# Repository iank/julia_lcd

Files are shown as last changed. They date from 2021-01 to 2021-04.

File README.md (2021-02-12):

# julia_lcd

TFT LCD panel, capacitive touch controller, Xilinx Cyclone IV FPGA, SDR SDRAM

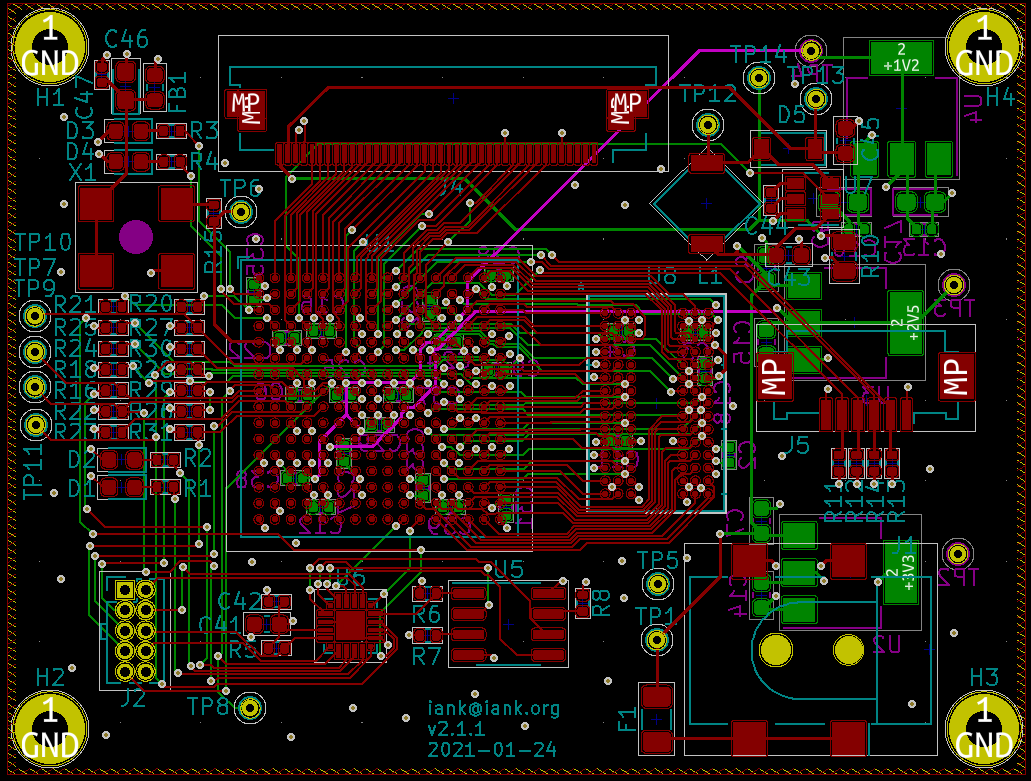
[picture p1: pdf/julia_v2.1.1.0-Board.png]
Board image

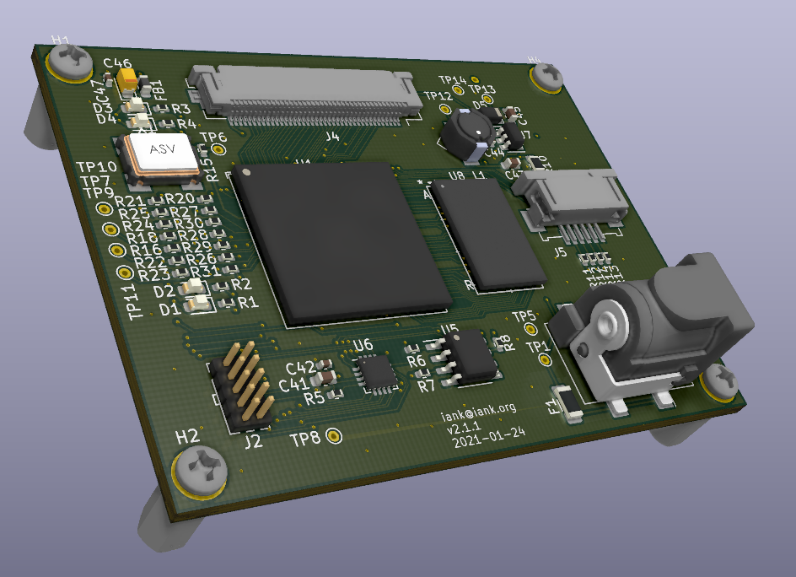
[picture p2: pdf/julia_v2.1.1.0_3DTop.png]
3D View (Top)

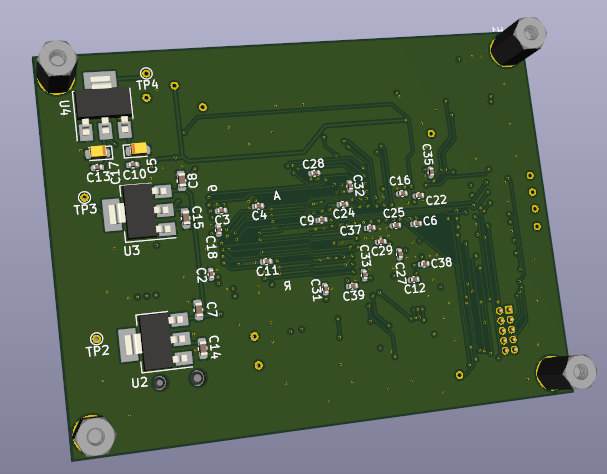
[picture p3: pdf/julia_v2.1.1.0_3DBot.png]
3D View (Bottom)


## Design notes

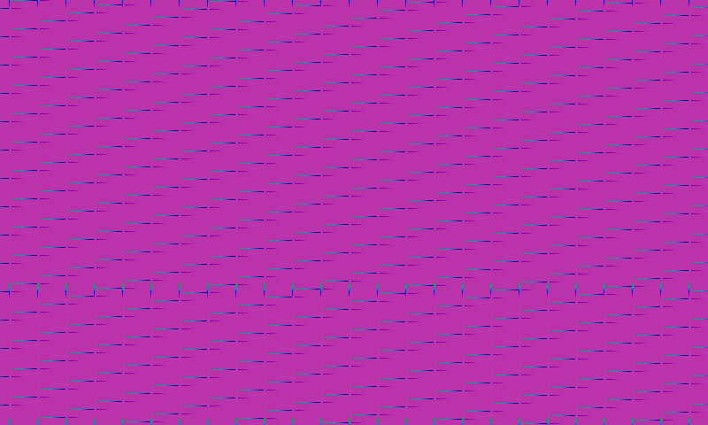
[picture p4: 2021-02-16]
src/fpga/img/verilog_sim.png

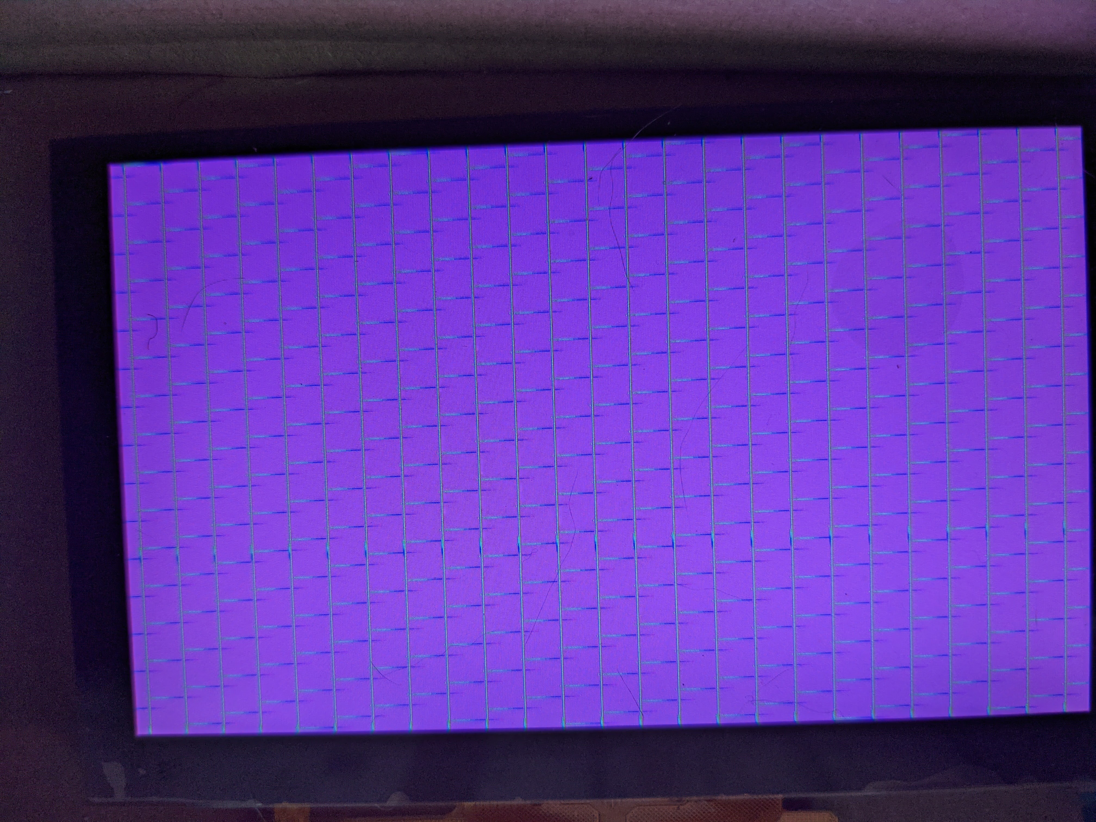
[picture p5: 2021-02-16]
src/fpga/img/actual.jpg

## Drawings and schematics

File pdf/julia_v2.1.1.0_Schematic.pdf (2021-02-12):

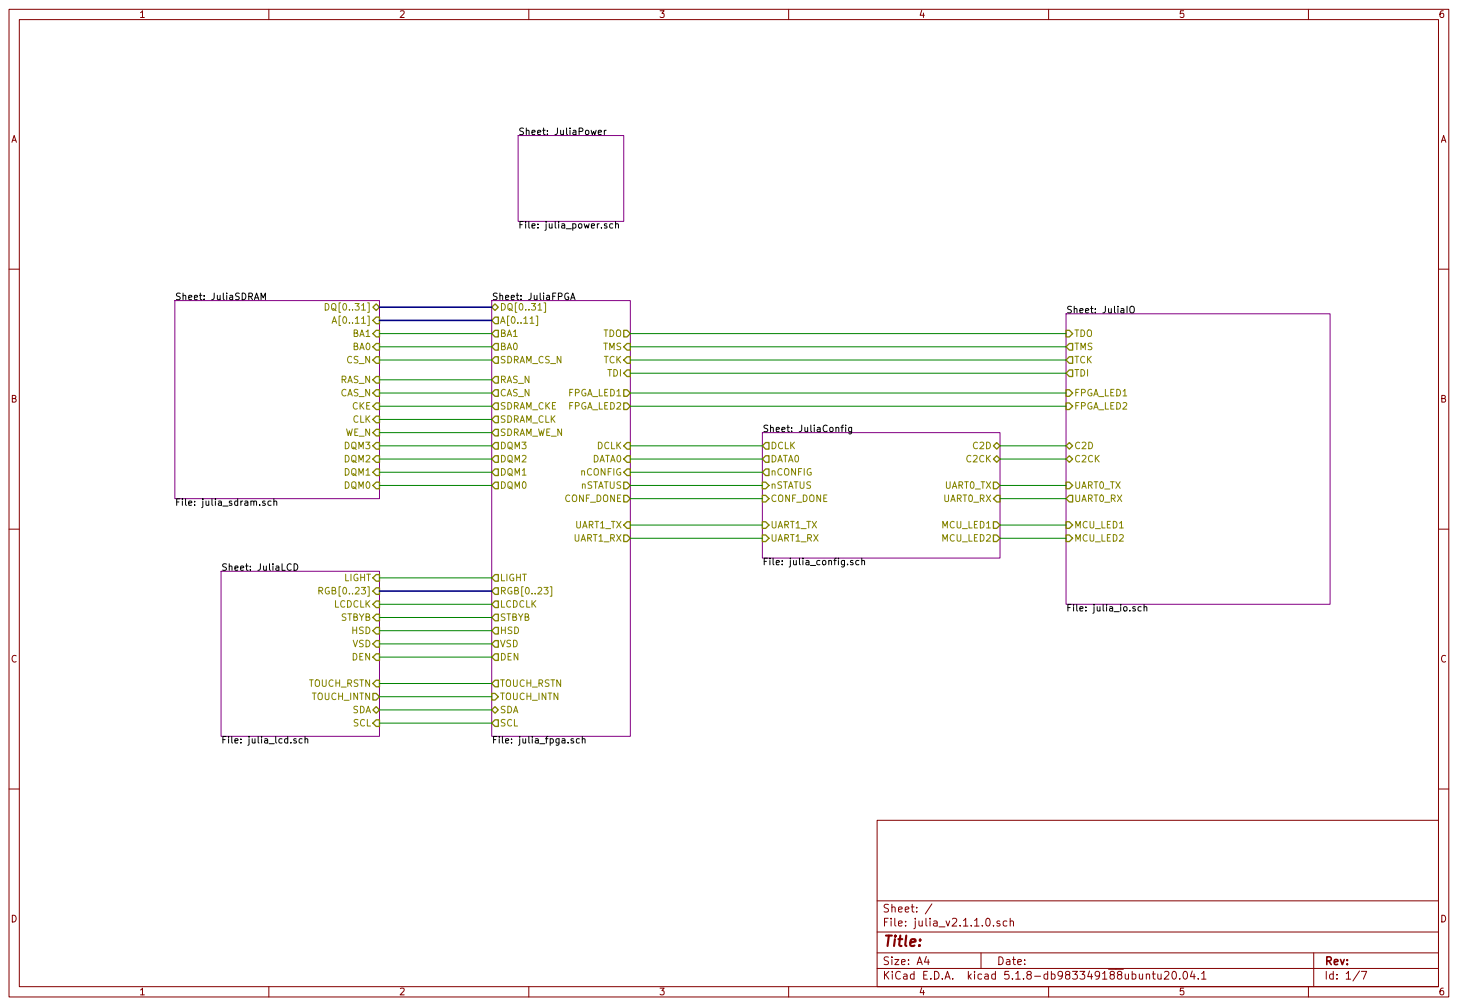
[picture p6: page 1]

Sheet: JuliaPower File: julia_power.sch Sheet: JuliaSDRAM

Sheet: JuliaIO
File: julia_io.sch TDI TMS
TCK

CKE CLK DQM3 DQM2 DQM1 DQM0 Sheet: JuliaLCD

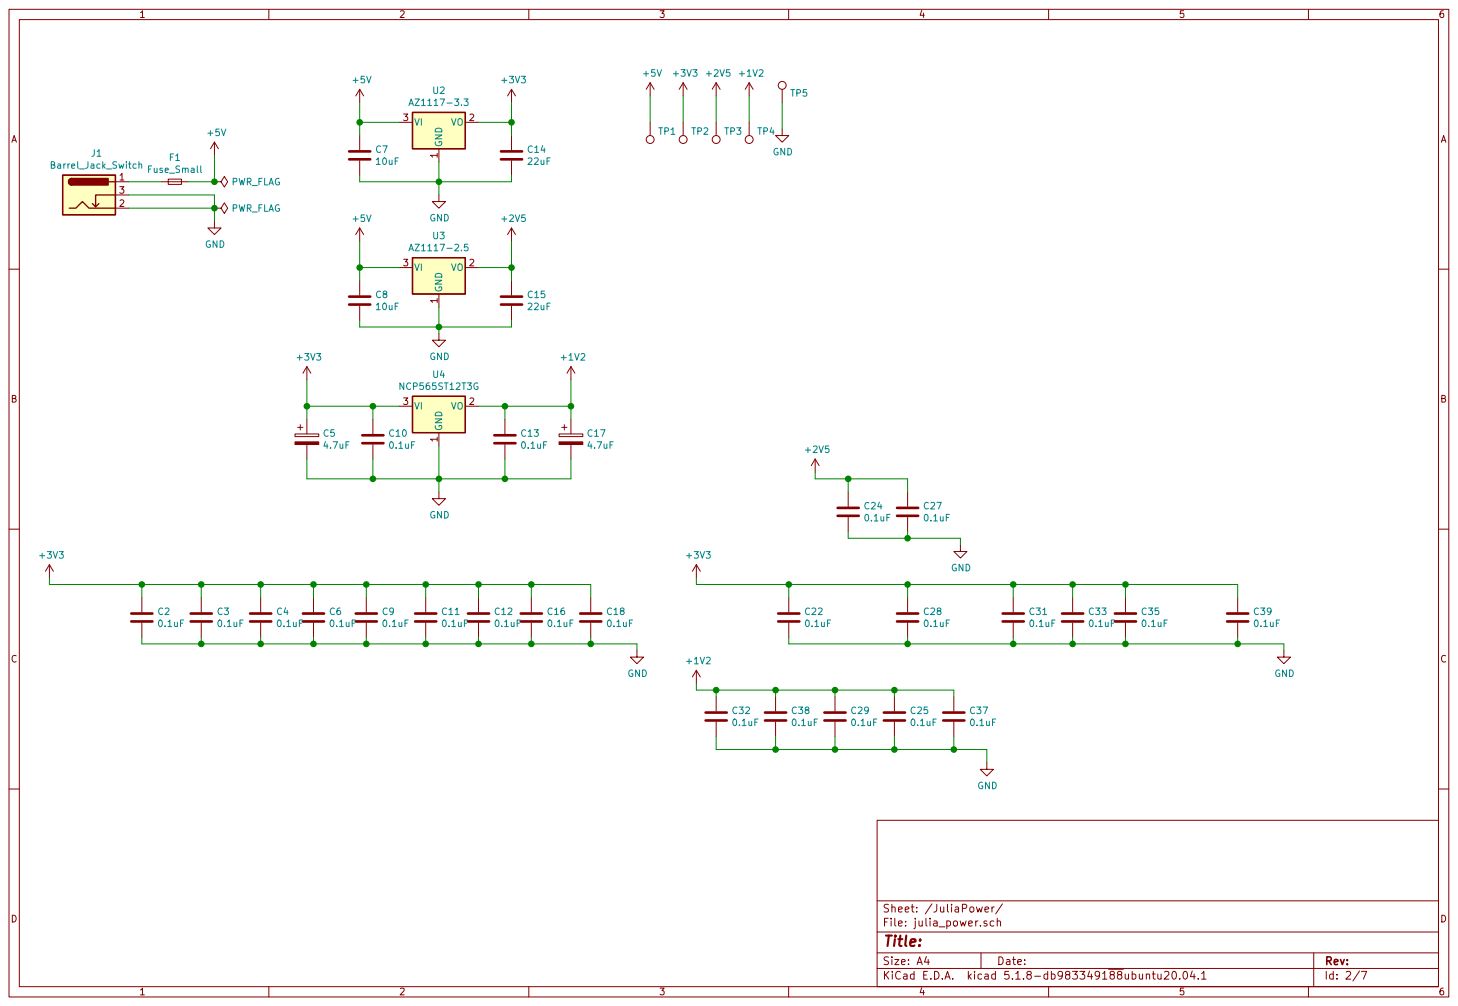
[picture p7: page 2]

File: julia_power.sch Sheet: /JuliaPower/
Id: 2/7 Title:

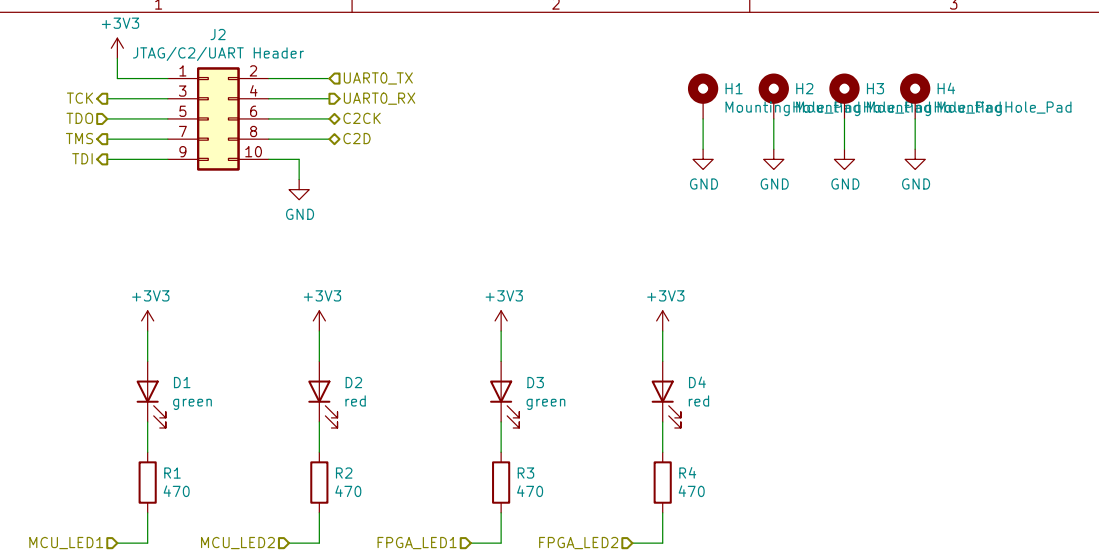
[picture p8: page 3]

File: julia_io.sch Sheet: /JuliaIO/
Id: 3/7 Title:

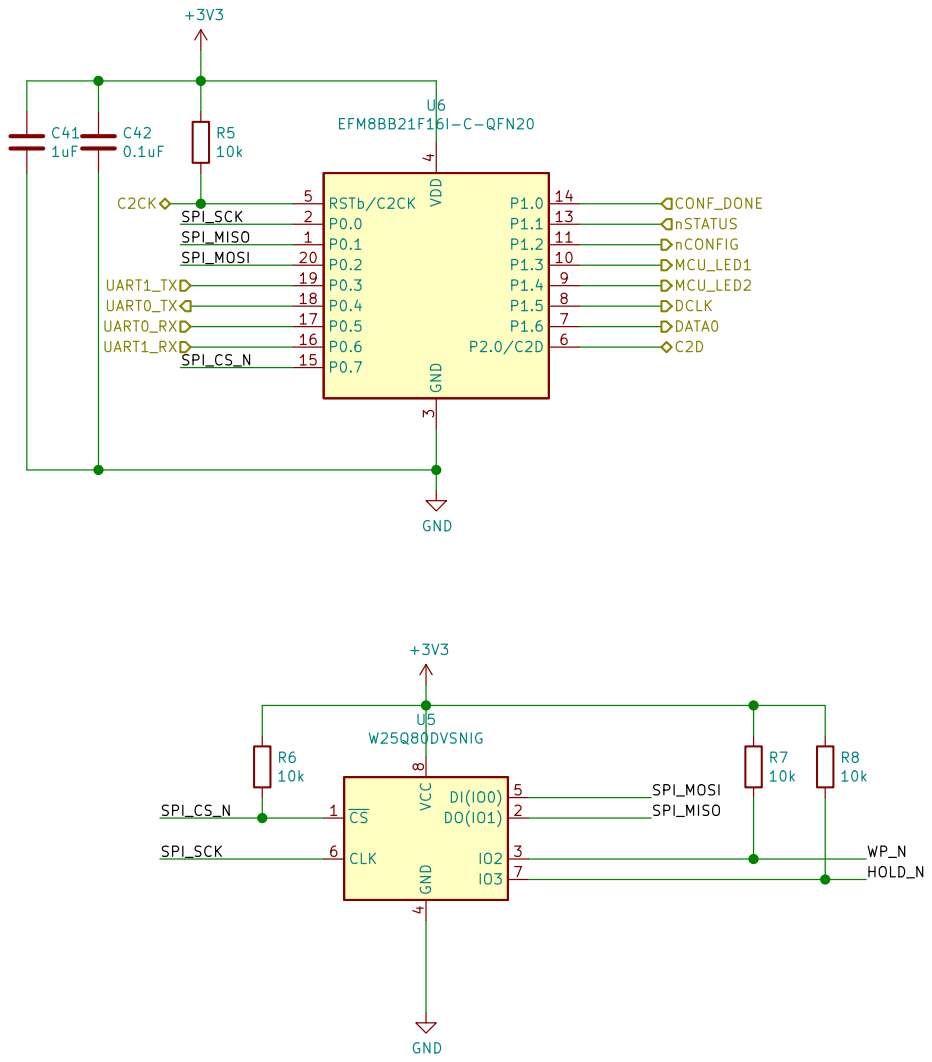
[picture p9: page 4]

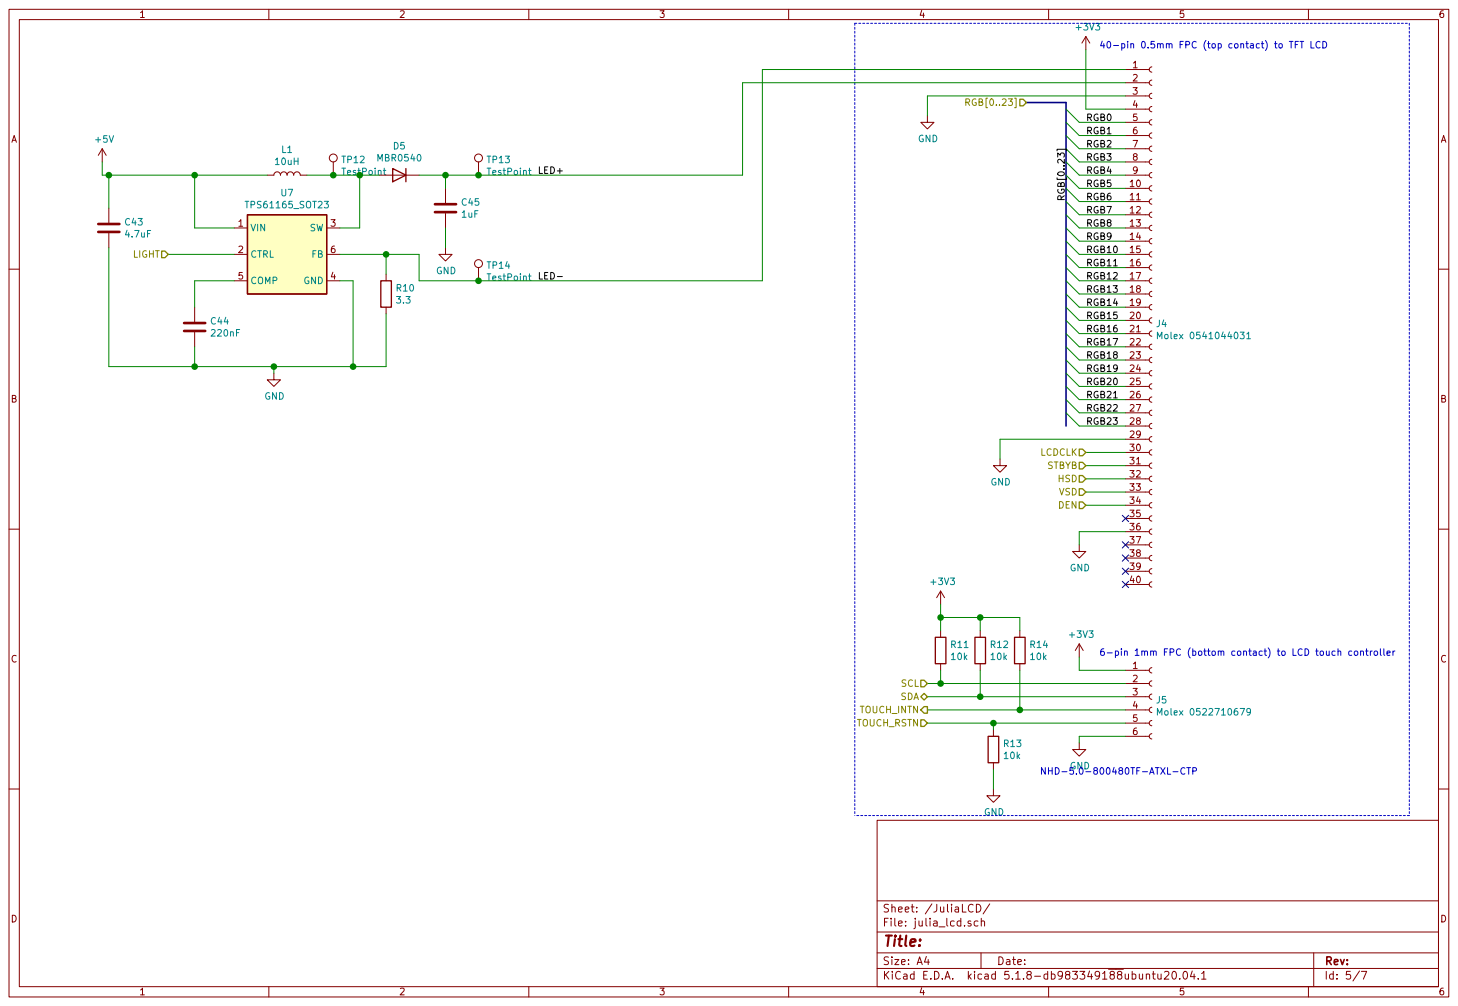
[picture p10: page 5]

40-pin 0.5mm FPC (top contact) to TFT LCD

6-pin 1mm FPC (bottom contact) to LCD touch controller NHD-5.0-800480TF-ATXL-CTP

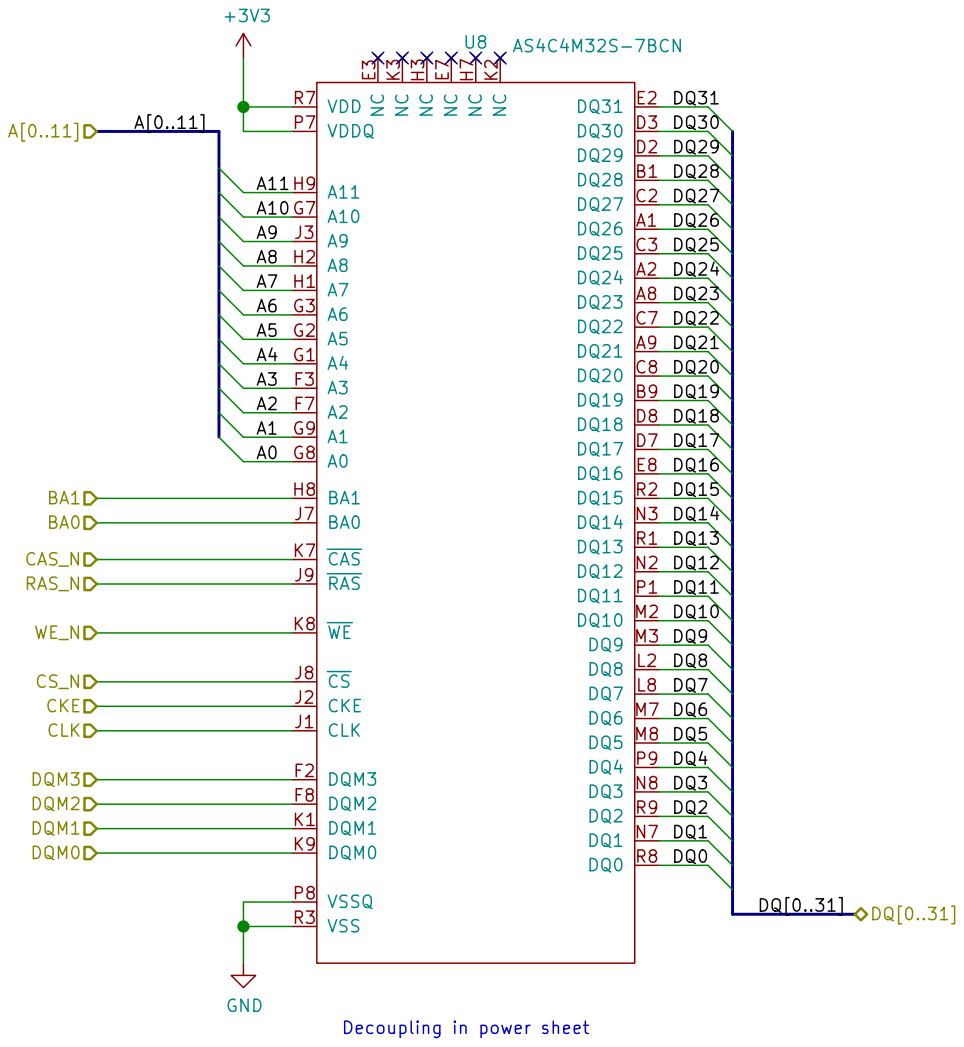
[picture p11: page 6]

File: julia_sdram.sch Sheet: /JuliaSDRAM/

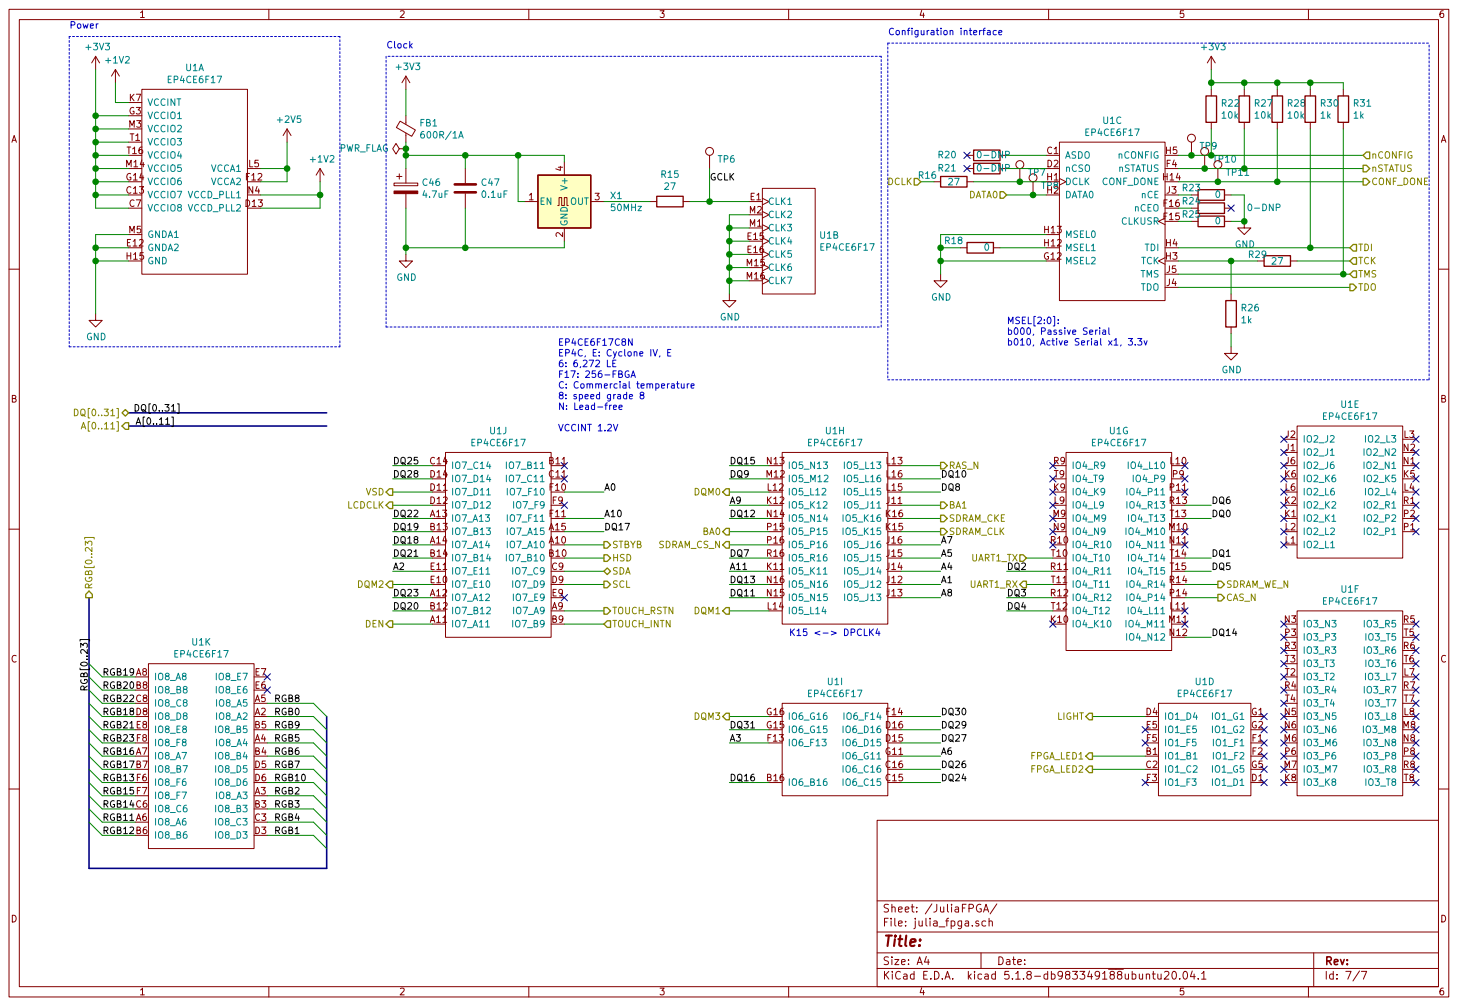
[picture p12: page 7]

File: julia_fpga.sch Sheet: /JuliaFPGA/
Id: 7/7 Title:

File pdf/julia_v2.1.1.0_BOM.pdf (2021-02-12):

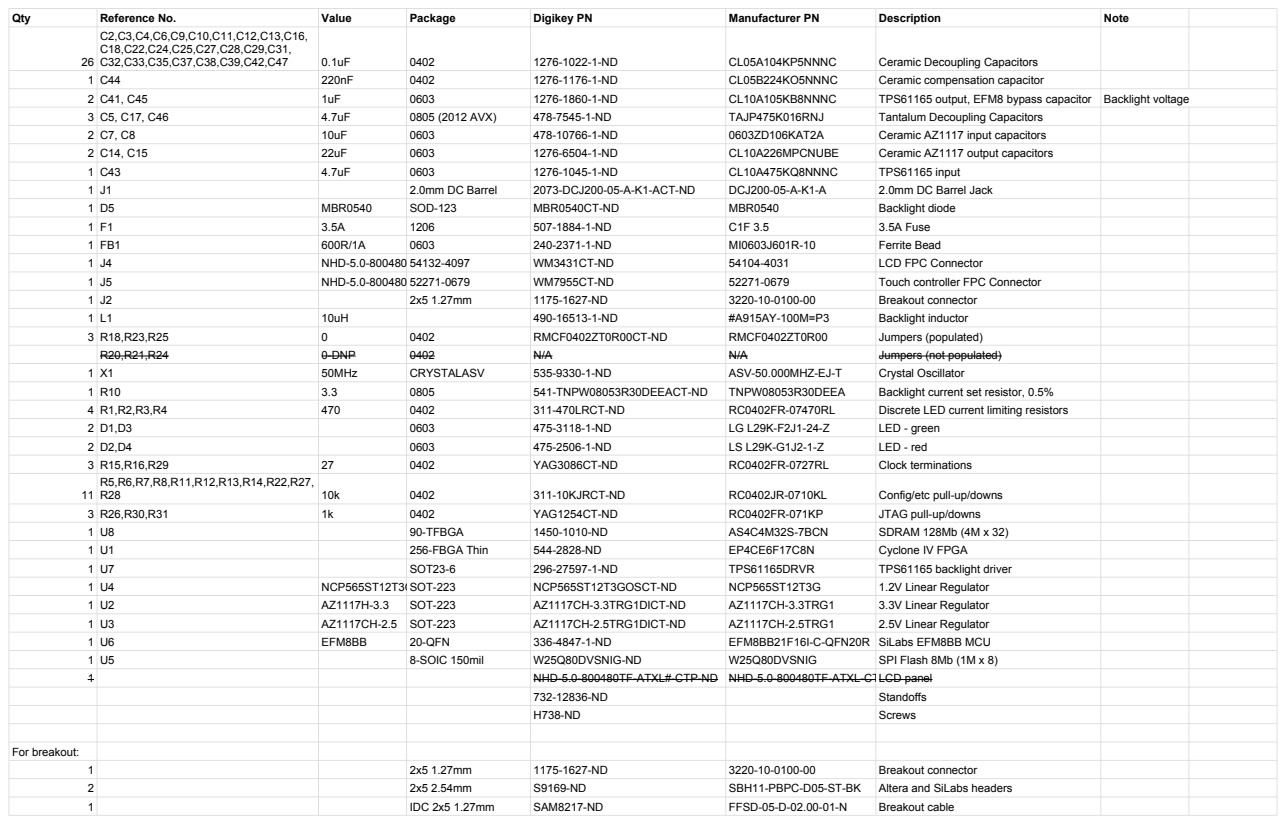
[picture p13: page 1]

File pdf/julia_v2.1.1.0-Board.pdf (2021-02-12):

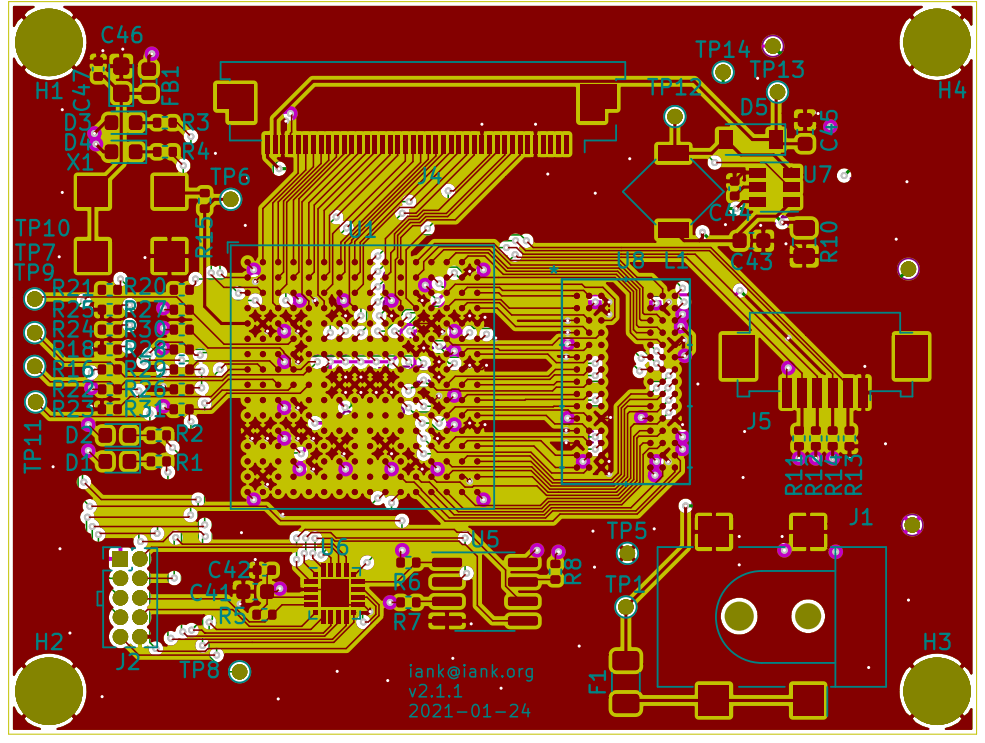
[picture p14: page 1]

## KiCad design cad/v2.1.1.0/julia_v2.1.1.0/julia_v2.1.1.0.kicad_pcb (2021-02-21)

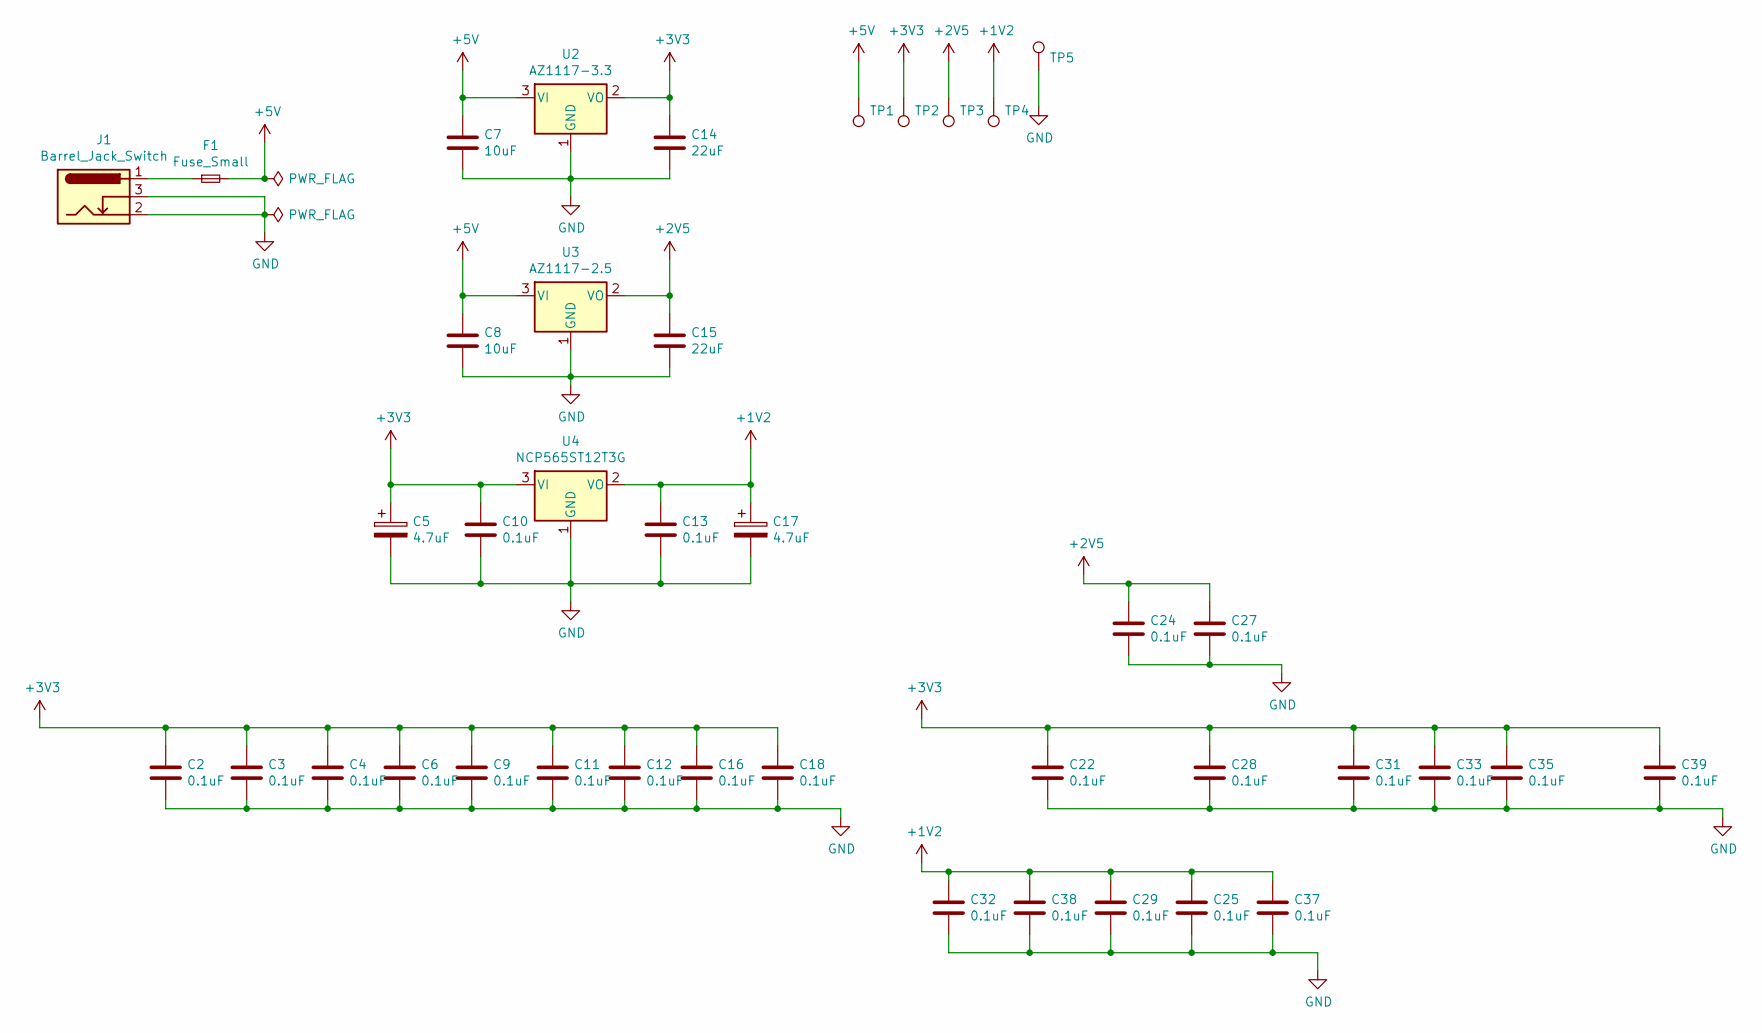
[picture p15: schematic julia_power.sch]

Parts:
C2, C3, C4, C6, C9, C10, C11, C12, C13, C16, C18, C22, C24, C25, C27, C28, C29, C31, C32, C33, C35, C37, C38, C39: 0.1uF; C_0402_1005Metric
C5, C17: 4.7uF; CP_EIA-2012-15_AVX-P
C7, C8: 10uF; C_0603_1608Metric
C14, C15: 22uF; C_0603_1608Metric
F1: Fuse_Small; Fuse_1206_3216Metric
J1: Barrel_Jack_Switch; BarrelJack_GCT_DCJ200-05-A-K1-A_SMD_Horizontal
TP1, TP2, TP3, TP4, TP5: TestPoint; TestPoint_THTPad_D1.0mm_Drill0.5mm
U2: AZ1117-3.3; SOT-223-3_TabPin2
U3: AZ1117-2.5; SOT-223-3_TabPin2
U4: NCP565ST12T3G; SOT-223-3_TabPin2

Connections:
+1V2: C13.1, C17.1, C25.1, C29.1, C32.1, C37.1, C38.1, TP4.1, U4.2 (VO); also elsewhere on the board
+2V5: C15.1, C24.1, C27.1, TP3.1, U3.2 (VO); also elsewhere on the board
+3V3: C2.1, C3.1, C4.1, C5.1, C6.1, C9.1, C10.1, C11.1, C12.1, C14.1, C16.1, C18.1, C22.1, C28.1, C31.1, C33.1, C35.1, C39.1, TP2.1, U2.2 (VO), U4.3 (VI); also elsewhere on the board
+5V: C7.1, C8.1, F1.2, TP1.1, U2.3 (VI), U3.3 (VI); also elsewhere on the board
GND: C2.2, C3.2, C4.2, C5.2, C6.2, C7.2, C8.2, C9.2, C10.2, C11.2, C12.2, C13.2, C14.2, C15.2, C16.2, C17.2, C18.2, C22.2, C24.2, C25.2, C27.2, C28.2, C29.2, C31.2, C32.2, C33.2, C35.2, C37.2, C38.2, C39.2, J1.2, J1.3, TP5.1, U2.1 (GND), U3.1 (GND), U4.1 (GND); also elsewhere on the board
unnamed: F1.1, J1.1

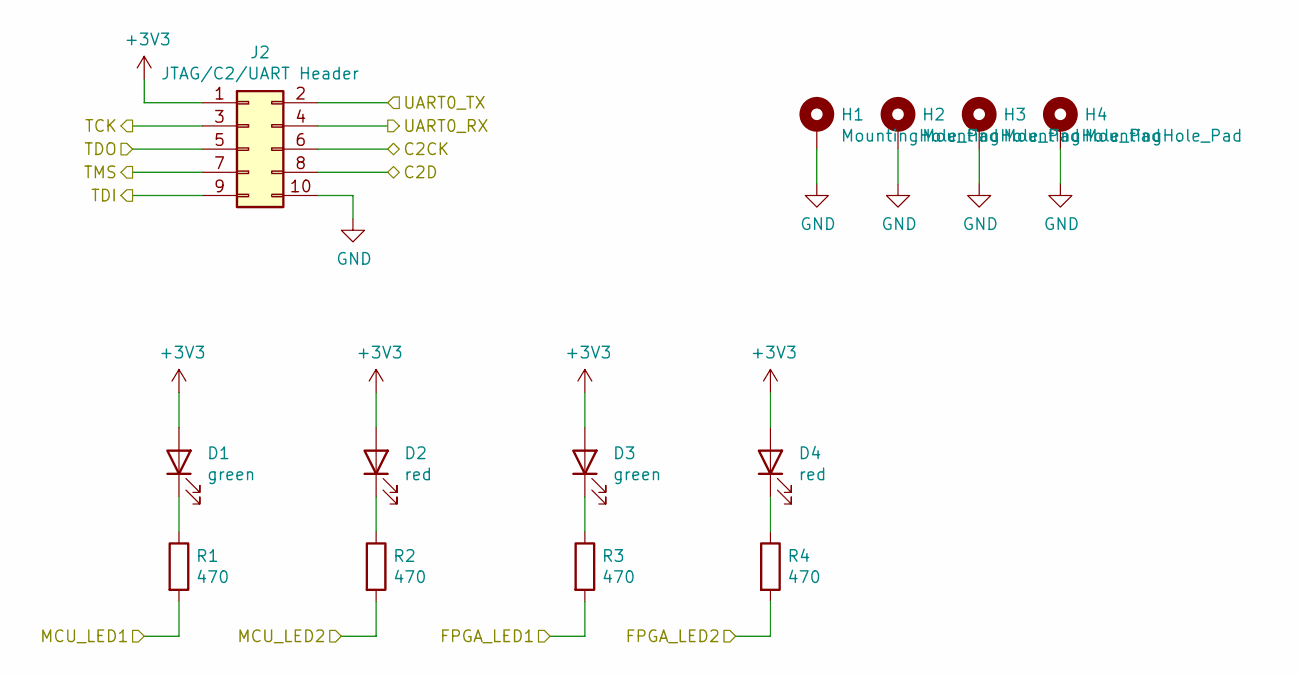
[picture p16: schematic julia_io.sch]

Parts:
D1, D3: green; LED_0603_1608Metric
D2, D4: red; LED_0603_1608Metric
H1, H2, H3, H4: MountingHole_Pad; MountingHole_2.2mm_M2_Pad
J2: JTAG/C2/UART Header; PinHeader_2x05_P1.27mm_Vertical
R1, R2, R3, R4: 470; R_0402_1005Metric

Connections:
+3V3: D1.2 (A), D2.2 (A), D3.2 (A), D4.2 (A), J2.1; also elsewhere on the board
/JuliaConfig/C2CK: J2.6; also elsewhere on the board
/JuliaConfig/C2D: J2.8; also elsewhere on the board
/JuliaConfig/MCU_LED1: R1.2; also elsewhere on the board
/JuliaConfig/MCU_LED2: R2.2; also elsewhere on the board
/JuliaConfig/UART0_RX: J2.4; also elsewhere on the board
/JuliaConfig/UART0_TX: J2.2; also elsewhere on the board
/JuliaFPGA/FPGA_LED1: R3.2; also elsewhere on the board
/JuliaFPGA/FPGA_LED2: R4.2; also elsewhere on the board
/JuliaFPGA/TCK: J2.3; also elsewhere on the board
/JuliaFPGA/TDI: J2.9; also elsewhere on the board
/JuliaFPGA/TDO: J2.5; also elsewhere on the board
/JuliaFPGA/TMS: J2.7; also elsewhere on the board
GND: H1.1, H2.1, H3.1, H4.1, J2.10; also elsewhere on the board
unnamed: D1.1 (K), R1.1
unnamed: D2.1 (K), R2.1
unnamed: D3.1 (K), R3.1
unnamed: D4.1 (K), R4.1

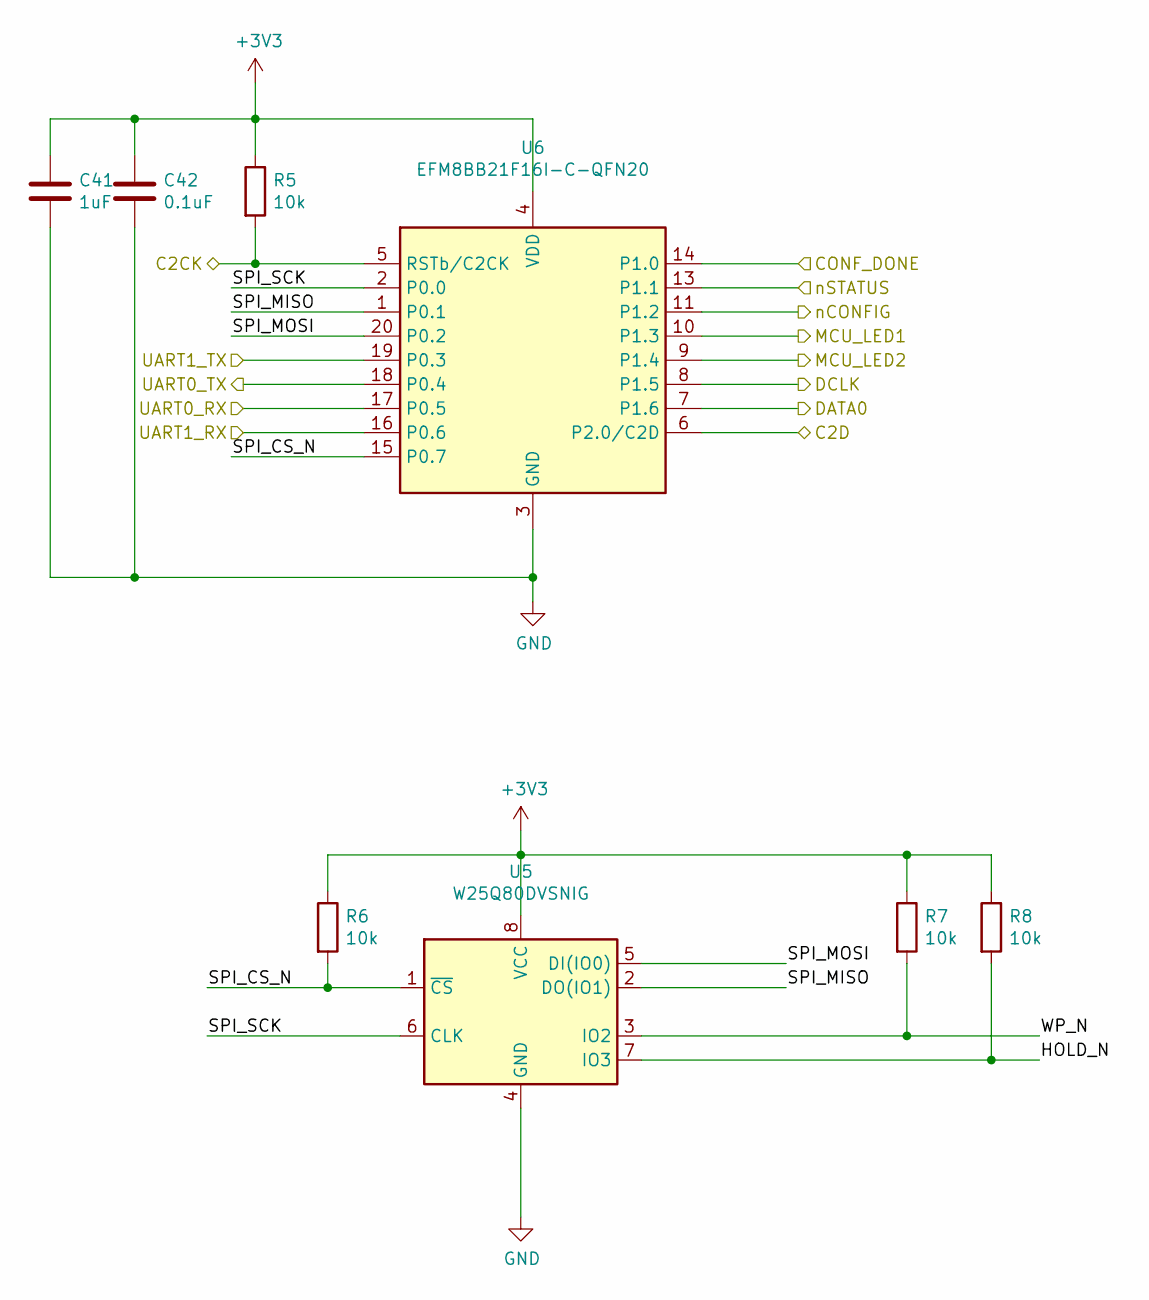
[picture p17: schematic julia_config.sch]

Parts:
C41: 1uF; C_0603_1608Metric
C42: 0.1uF; C_0402_1005Metric
R5, R6, R7, R8: 10k; R_0402_1005Metric
U5: W25Q80DVSNIG; SOIC-8_3.9x4.9mm_P1.27mm
U6: EFM8BB21F16I-C-QFN20; SiliconLabs_QFN-20-1EP_3x3mm_P0.5mm_EP1.8x1.8mm

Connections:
+3V3: C41.1, C42.1, R5.1, R6.1, R7.1, R8.1, U5.8 (VCC), U6.4 (VDD); also elsewhere on the board
/JuliaConfig/C2CK: R5.2, U6.5 (RSTb/C2CK); also elsewhere on the board
/JuliaConfig/C2D: U6.6 (P2.0/C2D); also elsewhere on the board
/JuliaConfig/CONF_DONE: U6.14 (P1.0); also elsewhere on the board
/JuliaConfig/DATA0: U6.7 (P1.6); also elsewhere on the board
/JuliaConfig/DCLK: U6.8 (P1.5); also elsewhere on the board
/JuliaConfig/HOLD_N: R8.2, U5.7 (IO3)
/JuliaConfig/MCU_LED1: U6.10 (P1.3); also elsewhere on the board
/JuliaConfig/MCU_LED2: U6.9 (P1.4); also elsewhere on the board
/JuliaConfig/SPI_CS_N: R6.2, U5.1 (~CS), U6.15 (P0.7)
/JuliaConfig/SPI_MISO: U5.2 (DO(IO1)), U6.1 (P0.1)
/JuliaConfig/SPI_MOSI: U5.5 (DI(IO0)), U6.20 (P0.2)
/JuliaConfig/SPI_SCK: U5.6 (CLK), U6.2 (P0.0)
/JuliaConfig/UART0_RX: U6.17 (P0.5); also elsewhere on the board
/JuliaConfig/UART0_TX: U6.18 (P0.4); also elsewhere on the board
/JuliaConfig/UART1_RX: U6.16 (P0.6); also elsewhere on the board
/JuliaConfig/UART1_TX: U6.19 (P0.3); also elsewhere on the board
/JuliaConfig/WP_N: R7.2, U5.3 (IO2)
/JuliaConfig/nCONFIG: U6.11 (P1.2); also elsewhere on the board
/JuliaConfig/nSTATUS: U6.13 (P1.1); also elsewhere on the board
GND: C41.2, C42.2, U5.4 (GND), U6.3 (GND), U6.12 (GND), U6.21 (GND); also elsewhere on the board

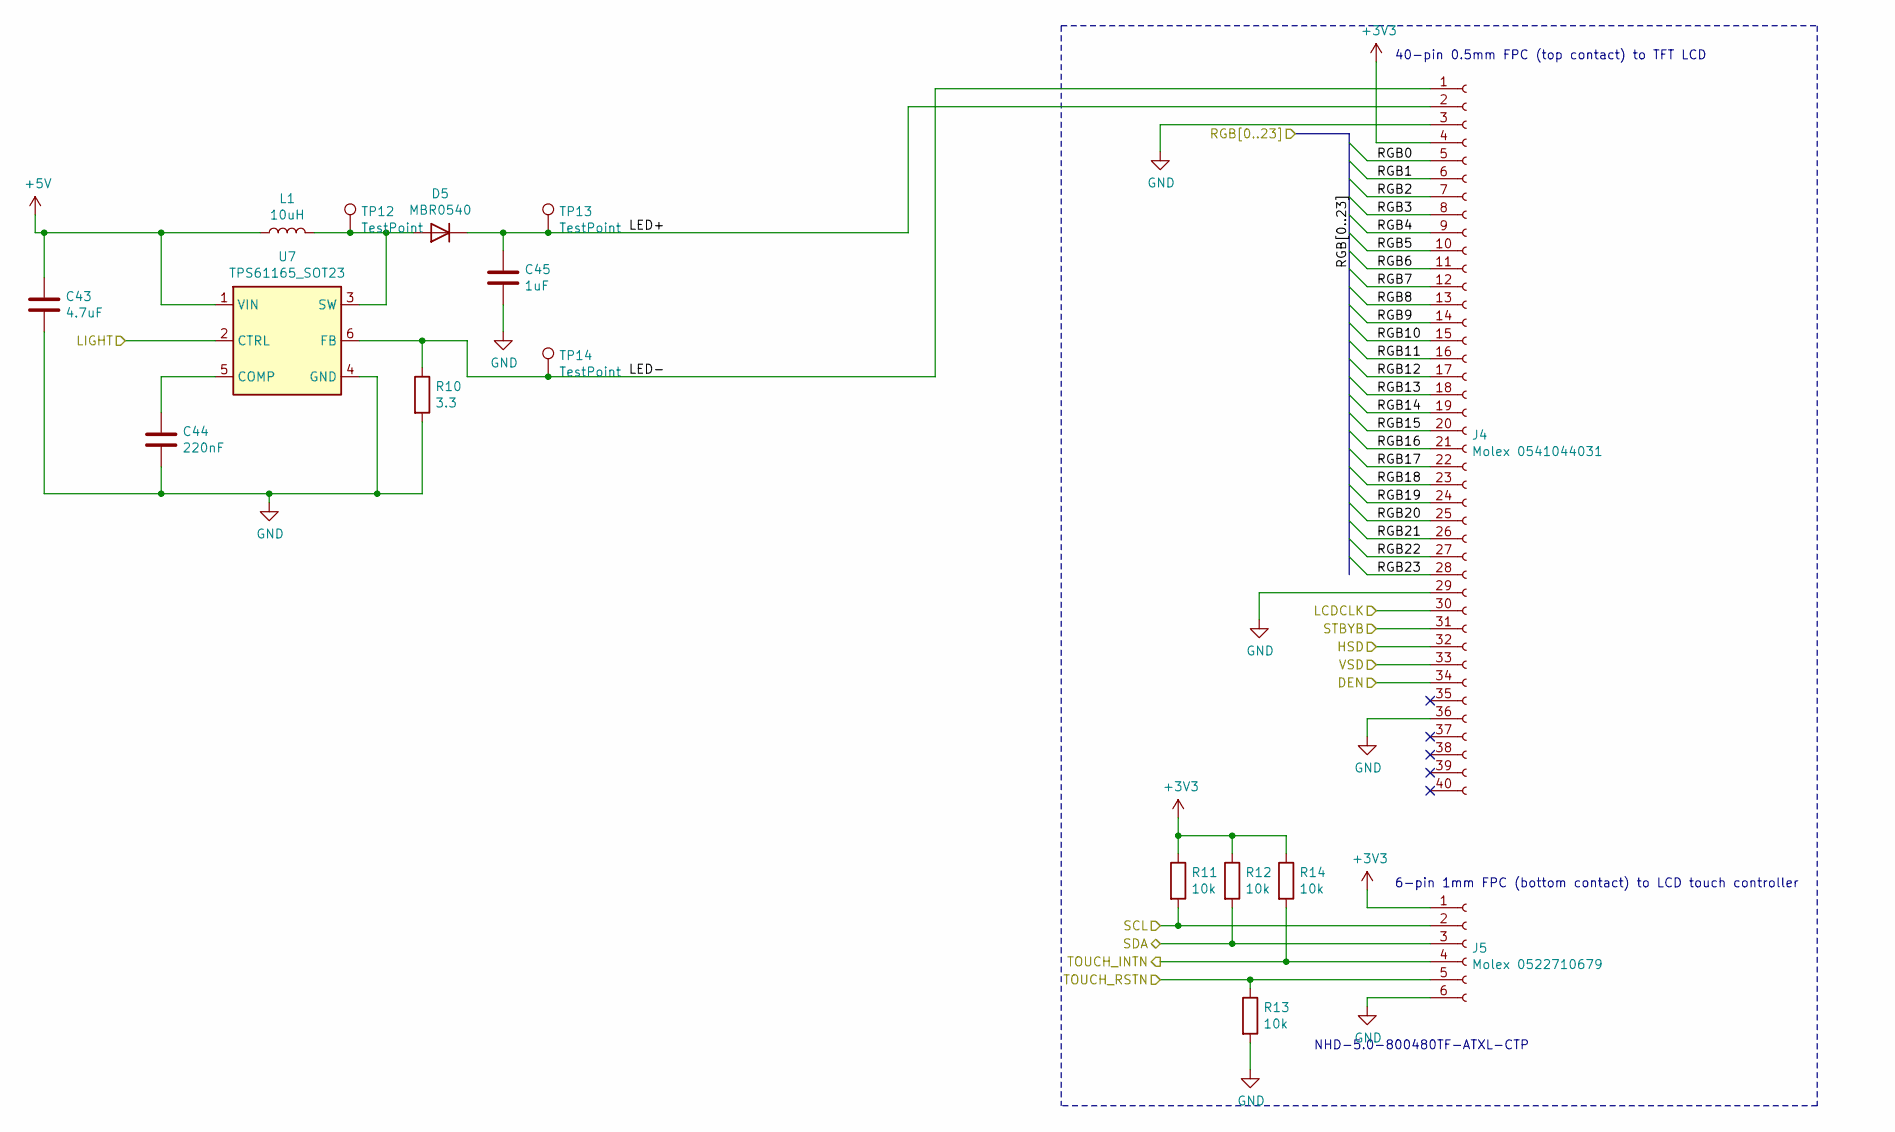
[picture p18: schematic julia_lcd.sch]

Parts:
C43: 4.7uF; C_0603_1608Metric
C44: 220nF; C_0402_1005Metric
C45: 1uF; C_0603_1608Metric
D5: MBR0540; D_SOD-123
J4: Molex 0541044031; Molex_54104-4031_1x40-P0.5mm_Horizontal
J5: Molex 0522710679; Molex_52271-0679_1x06-1MP_P1.00mm_Horizontal
L1: 10uH; Murata_D53LC_A915AY-100M
R10: 3.3; R_0805_2012Metric
R11, R12, R13, R14: 10k; R_0402_1005Metric
TP12, TP13, TP14: TestPoint; TestPoint_THTPad_D1.0mm_Drill0.5mm
U7: TPS61165_SOT23; SOT-23-6

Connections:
+3V3: J4.4, J5.1, R11.1, R12.1, R14.1; also elsewhere on the board
+5V: C43.1, L1.1, U7.1 (VIN); also elsewhere on the board
/JuliaFPGA/DEN: J4.34; also elsewhere on the board
/JuliaFPGA/HSD: J4.32; also elsewhere on the board
/JuliaFPGA/LCDCLK: J4.30; also elsewhere on the board
/JuliaFPGA/LIGHT: U7.2 (CTRL); also elsewhere on the board
/JuliaFPGA/RGB0: J4.5; also elsewhere on the board
/JuliaFPGA/RGB1: J4.6; also elsewhere on the board
/JuliaFPGA/RGB2: J4.7; also elsewhere on the board
/JuliaFPGA/RGB3: J4.8; also elsewhere on the board
/JuliaFPGA/RGB4: J4.9; also elsewhere on the board
/JuliaFPGA/RGB5: J4.10; also elsewhere on the board
/JuliaFPGA/RGB6: J4.11; also elsewhere on the board
/JuliaFPGA/RGB7: J4.12; also elsewhere on the board
/JuliaFPGA/RGB8: J4.13; also elsewhere on the board
/JuliaFPGA/RGB9: J4.14; also elsewhere on the board
/JuliaFPGA/RGB10: J4.15; also elsewhere on the board
/JuliaFPGA/RGB11: J4.16; also elsewhere on the board
/JuliaFPGA/RGB12: J4.17; also elsewhere on the board
/JuliaFPGA/RGB13: J4.18; also elsewhere on the board
/JuliaFPGA/RGB14: J4.19; also elsewhere on the board
/JuliaFPGA/RGB15: J4.20; also elsewhere on the board
/JuliaFPGA/RGB16: J4.21; also elsewhere on the board
/JuliaFPGA/RGB17: J4.22; also elsewhere on the board
/JuliaFPGA/RGB18: J4.23; also elsewhere on the board
/JuliaFPGA/RGB19: J4.24; also elsewhere on the board
/JuliaFPGA/RGB20: J4.25; also elsewhere on the board
/JuliaFPGA/RGB21: J4.26; also elsewhere on the board
/JuliaFPGA/RGB22: J4.27; also elsewhere on the board
/JuliaFPGA/RGB23: J4.28; also elsewhere on the board
/JuliaFPGA/SCL: J5.2, R11.2; also elsewhere on the board
/JuliaFPGA/SDA: J5.3, R12.2; also elsewhere on the board
/JuliaFPGA/STBYB: J4.31; also elsewhere on the board
/JuliaFPGA/TOUCH_INTN: J5.4, R14.2; also elsewhere on the board
/JuliaFPGA/TOUCH_RSTN: J5.5, R13.1; also elsewhere on the board
/JuliaFPGA/VSD: J4.33; also elsewhere on the board
/JuliaLCD/LED+: C45.1, D5.1 (K), J4.2, TP13.1
/JuliaLCD/LED-: J4.1, R10.1, TP14.1, U7.6 (FB)
GND: C43.2, C44.2, C45.2, J4.3, J4.29, J4.36, J5.6, R10.2, R13.2, U7.4 (GND); also elsewhere on the board
unnamed: C44.1, U7.5 (COMP)
unnamed: D5.2 (A), L1.2, TP12.1, U7.3 (SW)

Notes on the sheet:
40-pin 0.5mm FPC (top contact) to TFT LCD
NHD-5.0-800480TF-ATXL-CTP
6-pin 1mm FPC (bottom contact) to LCD touch controller

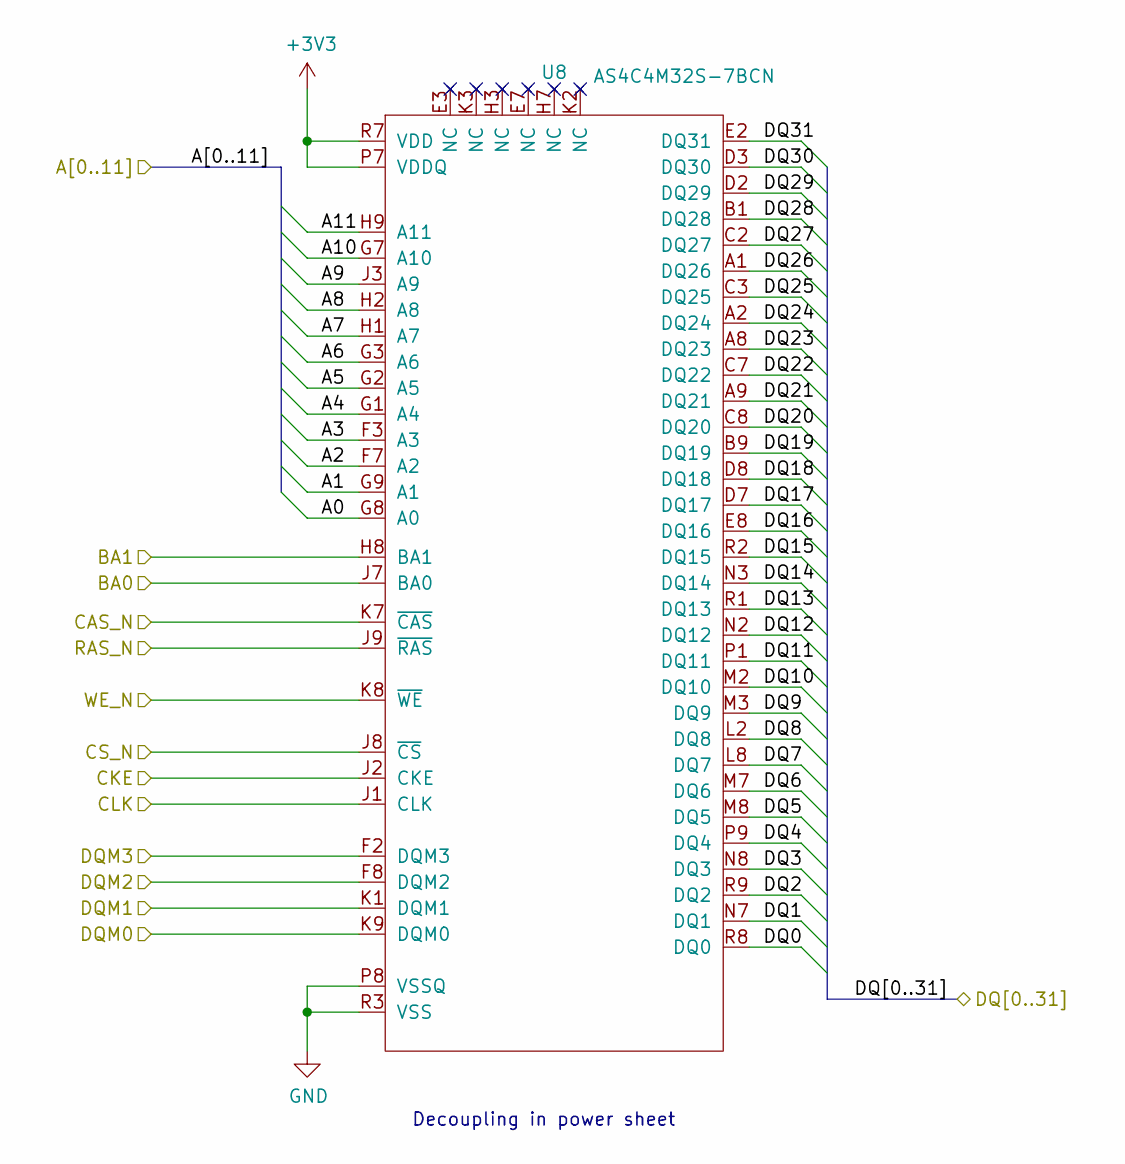
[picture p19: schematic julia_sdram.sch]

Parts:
U8: AS4C4M32S-7BCN

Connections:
+3V3: U8.A7 (VDD), U8.B2 (VDDQ), U8.B7 (VDDQ), U8.C9 (VDDQ), U8.D9 (VDDQ), U8.E1 (VDDQ), U8.F9 (VDD), U8.L1 (VDDQ), U8.L7 (VDD), U8.M9 (VDDQ), U8.N9 (VDDQ), U8.P2 (VDDQ), U8.P7 (VDDQ), U8.R7 (VDD); also elsewhere on the board
/JuliaFPGA/A0: U8.G8 (A0); also elsewhere on the board
/JuliaFPGA/A1: U8.G9 (A1); also elsewhere on the board
/JuliaFPGA/A2: U8.F7 (A2); also elsewhere on the board
/JuliaFPGA/A3: U8.F3 (A3); also elsewhere on the board
/JuliaFPGA/A4: U8.G1 (A4); also elsewhere on the board
/JuliaFPGA/A5: U8.G2 (A5); also elsewhere on the board
/JuliaFPGA/A6: U8.G3 (A6); also elsewhere on the board
/JuliaFPGA/A7: U8.H1 (A7); also elsewhere on the board
/JuliaFPGA/A8: U8.H2 (A8); also elsewhere on the board
/JuliaFPGA/A9: U8.J3 (A9); also elsewhere on the board
/JuliaFPGA/A10: U8.G7 (A10); also elsewhere on the board
/JuliaFPGA/A11: U8.H9 (A11); also elsewhere on the board
/JuliaFPGA/BA0: U8.J7 (BA0); also elsewhere on the board
/JuliaFPGA/BA1: U8.H8 (BA1); also elsewhere on the board
/JuliaFPGA/CAS_N: U8.K7 (~CAS~); also elsewhere on the board
/JuliaFPGA/DQ0: U8.R8 (DQ0); also elsewhere on the board
/JuliaFPGA/DQ1: U8.N7 (DQ1); also elsewhere on the board
/JuliaFPGA/DQ2: U8.R9 (DQ2); also elsewhere on the board
/JuliaFPGA/DQ3: U8.N8 (DQ3); also elsewhere on the board
/JuliaFPGA/DQ4: U8.P9 (DQ4); also elsewhere on the board
/JuliaFPGA/DQ5: U8.M8 (DQ5); also elsewhere on the board
/JuliaFPGA/DQ6: U8.M7 (DQ6); also elsewhere on the board
/JuliaFPGA/DQ7: U8.L8 (DQ7); also elsewhere on the board
/JuliaFPGA/DQ8: U8.L2 (DQ8); also elsewhere on the board
/JuliaFPGA/DQ9: U8.M3 (DQ9); also elsewhere on the board
/JuliaFPGA/DQ10: U8.M2 (DQ10); also elsewhere on the board
/JuliaFPGA/DQ11: U8.P1 (DQ11); also elsewhere on the board
/JuliaFPGA/DQ12: U8.N2 (DQ12); also elsewhere on the board
/JuliaFPGA/DQ13: U8.R1 (DQ13); also elsewhere on the board
/JuliaFPGA/DQ14: U8.N3 (DQ14); also elsewhere on the board
/JuliaFPGA/DQ15: U8.R2 (DQ15); also elsewhere on the board
/JuliaFPGA/DQ16: U8.E8 (DQ16); also elsewhere on the board
/JuliaFPGA/DQ17: U8.D7 (DQ17); also elsewhere on the board
/JuliaFPGA/DQ18: U8.D8 (DQ18); also elsewhere on the board
/JuliaFPGA/DQ19: U8.B9 (DQ19); also elsewhere on the board
/JuliaFPGA/DQ20: U8.C8 (DQ20); also elsewhere on the board
/JuliaFPGA/DQ21: U8.A9 (DQ21); also elsewhere on the board
/JuliaFPGA/DQ22: U8.C7 (DQ22); also elsewhere on the board
/JuliaFPGA/DQ23: U8.A8 (DQ23); also elsewhere on the board
/JuliaFPGA/DQ24: U8.A2 (DQ24); also elsewhere on the board
/JuliaFPGA/DQ25: U8.C3 (DQ25); also elsewhere on the board
/JuliaFPGA/DQ26: U8.A1 (DQ26); also elsewhere on the board
/JuliaFPGA/DQ27: U8.C2 (DQ27); also elsewhere on the board
/JuliaFPGA/DQ28: U8.B1 (DQ28); also elsewhere on the board
/JuliaFPGA/DQ29: U8.D2 (DQ29); also elsewhere on the board
/JuliaFPGA/DQ30: U8.D3 (DQ30); also elsewhere on the board
/JuliaFPGA/DQ31: U8.E2 (DQ31); also elsewhere on the board
/JuliaFPGA/DQM0: U8.K9 (DQM0); also elsewhere on the board
/JuliaFPGA/DQM1: U8.K1 (DQM1); also elsewhere on the board
/JuliaFPGA/DQM2: U8.F8 (DQM2); also elsewhere on the board
/JuliaFPGA/DQM3: U8.F2 (DQM3); also elsewhere on the board
/JuliaFPGA/RAS_N: U8.J9 (~RAS~); also elsewhere on the board
/JuliaFPGA/SDRAM_WE_N: U8.K8 (~WE~); also elsewhere on the board
/JuliaSDRAM/CKE: U8.J2 (CKE); also elsewhere on the board
/JuliaSDRAM/CLK: U8.J1 (CLK); also elsewhere on the board
/JuliaSDRAM/CS_N: U8.J8 (~CS~); also elsewhere on the board
GND: U8.A3 (VSS), U8.B3 (VSSQ), U8.B8 (VSSQ), U8.C1 (VSSQ), U8.D1 (VSSQ), U8.E9 (VSSQ), U8.F1 (VSS), U8.L3 (VSS), U8.L9 (VSSQ), U8.M1 (VSSQ), U8.N1 (VSSQ), U8.P3 (VSSQ), U8.P8 (VSSQ), U8.R3 (VSS); also elsewhere on the board

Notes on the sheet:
Decoupling in power sheet

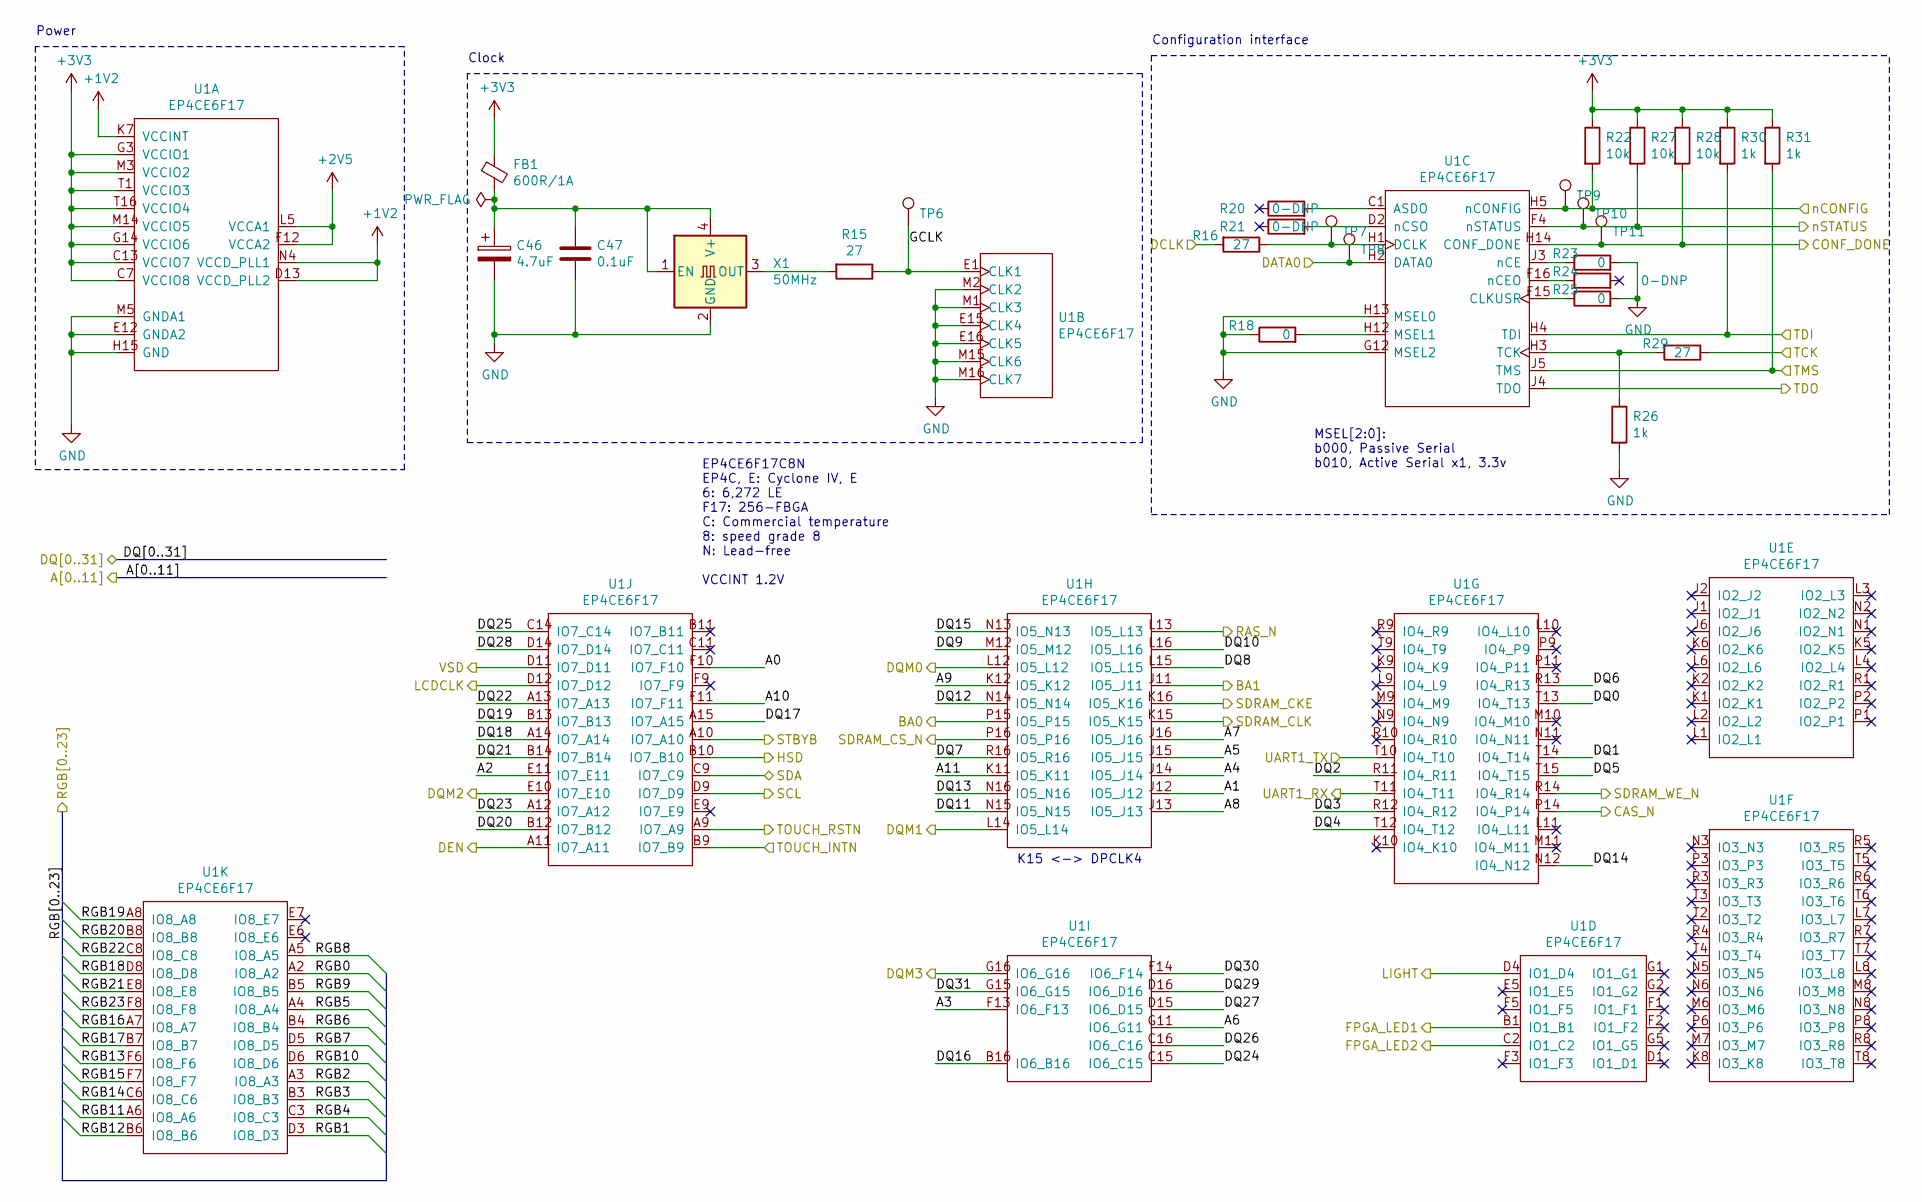
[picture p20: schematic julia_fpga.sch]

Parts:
C46: 4.7uF; CP_EIA-2012-15_AVX-P
C47: 0.1uF; C_0402_1005Metric
FB1: 600R/1A; L_0603_1608Metric
R15, R16, R29: 27; R_0402_1005Metric
R18, R23, R25: 0; R_0402_1005Metric
R20, R21, R24: 0-DNP; R_0402_1005Metric
R22, R27, R28: 10k; R_0402_1005Metric
R26, R30, R31: 1k; R_0402_1005Metric
TP6, TP7, TP8, TP9, TP10, TP11: TestPoint; TestPoint_THTPad_D1.0mm_Drill0.5mm
U1: EP4CE6F17; BGA-256_17.0x17.0mm_Layout16x16_P1.0mm_Ball0.5mm_Pad0.4mm_N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
X1: 50MHz; Oscillator_SMD_EuroQuartz_XO91-4Pin_7.0x5.0mm

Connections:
+1V2: U1.D13 (VCCD_PLL2), U1.G6 (VCCINT), U1.G7 (VCCINT), U1.G8 (VCCINT), U1.G9 (VCCINT), U1.G10 (VCCINT), U1.H6 (VCCINT), U1.H11 (VCCINT), U1.K7 (VCCINT), U1.N4 (VCCD_PLL1); also elsewhere on the board
+2V5: U1.F12 (VCCA2), U1.L5 (VCCA1); also elsewhere on the board
+3V3: FB1.1, R22.1, R27.1, R28.1, R30.1, R31.1, U1.A1 (VCCIO8), U1.A16 (VCCIO7), U1.C4 (VCCIO8), U1.C7 (VCCIO8), U1.C10 (VCCIO7), U1.C13 (VCCIO7), U1.E3 (VCCIO1), U1.E14 (VCCIO6), U1.G3 (VCCIO1), U1.G14 (VCCIO6), U1.K3 (VCCIO2), U1.K14 (VCCIO5), U1.M3 (VCCIO2), U1.M14 (VCCIO5), U1.P4 (VCCIO3), U1.P7 (VCCIO3), U1.P10 (VCCIO4), U1.P13 (VCCIO4), U1.T1 (VCCIO3), U1.T16 (VCCIO4); also elsewhere on the board
/JuliaConfig/CONF_DONE: R28.2, TP11.1, U1.H14 (CONF_DONE); also elsewhere on the board
/JuliaConfig/DATA0: TP8.1, U1.H2 (DATA0); also elsewhere on the board
/JuliaConfig/DCLK: R16.2; also elsewhere on the board
/JuliaConfig/UART1_RX: U1.T11 (IO4_T11); also elsewhere on the board
/JuliaConfig/UART1_TX: U1.T10 (IO4_T10); also elsewhere on the board
/JuliaConfig/nCONFIG: R22.2, TP9.1, U1.H5 (nCONFIG); also elsewhere on the board
/JuliaConfig/nSTATUS: R27.2, TP10.1, U1.F4 (nSTATUS); also elsewhere on the board
/JuliaFPGA/A0: U1.F10 (IO7_F10); also elsewhere on the board
/JuliaFPGA/A1: U1.J12 (IO5_J12); also elsewhere on the board
/JuliaFPGA/A2: U1.E11 (IO7_E11); also elsewhere on the board
/JuliaFPGA/A3: U1.F13 (IO6_F13); also elsewhere on the board
/JuliaFPGA/A4: U1.J14 (IO5_J14); also elsewhere on the board
/JuliaFPGA/A5: U1.J15 (IO5_J15); also elsewhere on the board
/JuliaFPGA/A6: U1.G11 (IO6_G11); also elsewhere on the board
/JuliaFPGA/A7: U1.J16 (IO5_J16); also elsewhere on the board
/JuliaFPGA/A8: U1.J13 (IO5_J13); also elsewhere on the board
/JuliaFPGA/A9: U1.K12 (IO5_K12); also elsewhere on the board
/JuliaFPGA/A10: U1.F11 (IO7_F11); also elsewhere on the board
/JuliaFPGA/A11: U1.K11 (IO5_K11); also elsewhere on the board
/JuliaFPGA/BA0: U1.P15 (IO5_P15); also elsewhere on the board
/JuliaFPGA/BA1: U1.J11 (IO5_J11); also elsewhere on the board
/JuliaFPGA/CAS_N: U1.P14 (IO4_P14); also elsewhere on the board
/JuliaFPGA/DEN: U1.A11 (IO7_A11); also elsewhere on the board
/JuliaFPGA/DQ0: U1.T13 (IO4_T13); also elsewhere on the board
/JuliaFPGA/DQ1: U1.T14 (IO4_T14); also elsewhere on the board
/JuliaFPGA/DQ2: U1.R11 (IO4_R11); also elsewhere on the board
/JuliaFPGA/DQ3: U1.R12 (IO4_R12); also elsewhere on the board
/JuliaFPGA/DQ4: U1.T12 (IO4_T12); also elsewhere on the board
/JuliaFPGA/DQ5: U1.T15 (IO4_T15); also elsewhere on the board
/JuliaFPGA/DQ6: U1.R13 (IO4_R13); also elsewhere on the board
/JuliaFPGA/DQ7: U1.R16 (IO5_R16); also elsewhere on the board
/JuliaFPGA/DQ8: U1.L15 (IO5_L15); also elsewhere on the board
/JuliaFPGA/DQ9: U1.M12 (IO5_M12); also elsewhere on the board
/JuliaFPGA/DQ10: U1.L16 (IO5_L16); also elsewhere on the board
/JuliaFPGA/DQ11: U1.N15 (IO5_N15); also elsewhere on the board
/JuliaFPGA/DQ12: U1.N14 (IO5_N14); also elsewhere on the board
/JuliaFPGA/DQ13: U1.N16 (IO5_N16); also elsewhere on the board
/JuliaFPGA/DQ14: U1.N12 (IO4_N12); also elsewhere on the board
/JuliaFPGA/DQ15: U1.N13 (IO5_N13); also elsewhere on the board
/JuliaFPGA/DQ16: U1.B16 (IO6_B16); also elsewhere on the board
/JuliaFPGA/DQ17: U1.A15 (IO7_A15); also elsewhere on the board
/JuliaFPGA/DQ18: U1.A14 (IO7_A14); also elsewhere on the board
/JuliaFPGA/DQ19: U1.B13 (IO7_B13); also elsewhere on the board
/JuliaFPGA/DQ20: U1.B12 (IO7_B12); also elsewhere on the board
/JuliaFPGA/DQ21: U1.B14 (IO7_B14); also elsewhere on the board
/JuliaFPGA/DQ22: U1.A13 (IO7_A13); also elsewhere on the board
/JuliaFPGA/DQ23: U1.A12 (IO7_A12); also elsewhere on the board
/JuliaFPGA/DQ24: U1.C15 (IO6_C15); also elsewhere on the board
/JuliaFPGA/DQ25: U1.C14 (IO7_C14); also elsewhere on the board
/JuliaFPGA/DQ26: U1.C16 (IO6_C16); also elsewhere on the board
/JuliaFPGA/DQ27: U1.D15 (IO6_D15); also elsewhere on the board
/JuliaFPGA/DQ28: U1.D14 (IO7_D14); also elsewhere on the board
/JuliaFPGA/DQ29: U1.D16 (IO6_D16); also elsewhere on the board
/JuliaFPGA/DQ30: U1.F14 (IO6_F14); also elsewhere on the board
/JuliaFPGA/DQ31: U1.G15 (IO6_G15); also elsewhere on the board
/JuliaFPGA/DQM0: U1.L12 (IO5_L12); also elsewhere on the board
/JuliaFPGA/DQM1: U1.L14 (IO5_L14); also elsewhere on the board
/JuliaFPGA/DQM2: U1.E10 (IO7_E10); also elsewhere on the board
/JuliaFPGA/DQM3: U1.G16 (IO6_G16); also elsewhere on the board
/JuliaFPGA/FPGA_LED1: U1.B1 (IO1_B1); also elsewhere on the board
/JuliaFPGA/FPGA_LED2: U1.C2 (IO1_C2); also elsewhere on the board
/JuliaFPGA/GCLK: R15.1, TP6.1, U1.E1 (CLK1)
/JuliaFPGA/HSD: U1.B10 (IO7_B10); also elsewhere on the board
/JuliaFPGA/LCDCLK: U1.D12 (IO7_D12); also elsewhere on the board
/JuliaFPGA/LIGHT: U1.D4 (IO1_D4); also elsewhere on the board
/JuliaFPGA/RAS_N: U1.L13 (IO5_L13); also elsewhere on the board
/JuliaFPGA/RGB0: U1.A2 (IO8_A2); also elsewhere on the board
/JuliaFPGA/RGB1: U1.D3 (IO8_D3); also elsewhere on the board
/JuliaFPGA/RGB2: U1.A3 (IO8_A3); also elsewhere on the board
/JuliaFPGA/RGB3: U1.B3 (IO8_B3); also elsewhere on the board
/JuliaFPGA/RGB4: U1.C3 (IO8_C3); also elsewhere on the board
/JuliaFPGA/RGB5: U1.A4 (IO8_A4); also elsewhere on the board
/JuliaFPGA/RGB6: U1.B4 (IO8_B4); also elsewhere on the board
/JuliaFPGA/RGB7: U1.D5 (IO8_D5); also elsewhere on the board
/JuliaFPGA/RGB8: U1.A5 (IO8_A5); also elsewhere on the board
/JuliaFPGA/RGB9: U1.B5 (IO8_B5); also elsewhere on the board
/JuliaFPGA/RGB10: U1.D6 (IO8_D6); also elsewhere on the board
/JuliaFPGA/RGB11: U1.A6 (IO8_A6); also elsewhere on the board
/JuliaFPGA/RGB12: U1.B6 (IO8_B6); also elsewhere on the board
/JuliaFPGA/RGB13: U1.F6 (IO8_F6); also elsewhere on the board
/JuliaFPGA/RGB14: U1.C6 (IO8_C6); also elsewhere on the board
/JuliaFPGA/RGB15: U1.F7 (IO8_F7); also elsewhere on the board
/JuliaFPGA/RGB16: U1.A7 (IO8_A7); also elsewhere on the board
/JuliaFPGA/RGB17: U1.B7 (IO8_B7); also elsewhere on the board
/JuliaFPGA/RGB18: U1.D8 (IO8_D8); also elsewhere on the board
/JuliaFPGA/RGB19: U1.A8 (IO8_A8); also elsewhere on the board
/JuliaFPGA/RGB20: U1.B8 (IO8_B8); also elsewhere on the board
/JuliaFPGA/RGB21: U1.E8 (IO8_E8); also elsewhere on the board
/JuliaFPGA/RGB22: U1.C8 (IO8_C8); also elsewhere on the board
/JuliaFPGA/RGB23: U1.F8 (IO8_F8); also elsewhere on the board
/JuliaFPGA/SCL: U1.D9 (IO7_D9); also elsewhere on the board
/JuliaFPGA/SDA: U1.C9 (IO7_C9); also elsewhere on the board
/JuliaFPGA/SDRAM_WE_N: U1.R14 (IO4_R14); also elsewhere on the board
/JuliaFPGA/STBYB: U1.A10 (IO7_A10); also elsewhere on the board
/JuliaFPGA/TCK: R29.1; also elsewhere on the board
/JuliaFPGA/TDI: R30.2, U1.H4 (TDI); also elsewhere on the board
/JuliaFPGA/TDO: U1.J4 (TDO); also elsewhere on the board
/JuliaFPGA/TMS: R31.2, U1.J5 (TMS); also elsewhere on the board
/JuliaFPGA/TOUCH_INTN: U1.B9 (IO7_B9); also elsewhere on the board
/JuliaFPGA/TOUCH_RSTN: U1.A9 (IO7_A9); also elsewhere on the board
/JuliaFPGA/VSD: U1.D11 (IO7_D11); also elsewhere on the board
/JuliaSDRAM/CKE: U1.K16 (IO5_K16); also elsewhere on the board
/JuliaSDRAM/CLK: U1.K15 (IO5_K15); also elsewhere on the board
/JuliaSDRAM/CS_N: U1.P16 (IO5_P16); also elsewhere on the board
GND: C46.2, C47.2, R18.1, R23.2, R25.2, R26.2, U1.B2 (GND), U1.B15 (GND), U1.C5 (GND), U1.C12 (GND), U1.D7 (GND), U1.D10 (GND), U1.E2 (GND), U1.E4 (GND), U1.E12 (GNDA2), U1.E13 (GND), U1.E15 (CLK4), U1.E16 (CLK5), U1.G4 (GND), U1.G12 (MSEL2), U1.G13 (GND), U1.H7 (GND), U1.H8 (GND), U1.H9 (GND), U1.H10 (GND), U1.H13 (MSEL0), U1.H15 (GND), U1.H16 (GND), U1.J7 (GND), U1.J8 (GND), U1.J9 (GND), U1.J10 (GND), U1.K4 (GND), U1.K13 (GND), U1.M1 (CLK3), U1.M2 (CLK2), U1.M4 (GND), U1.M5 (GNDA1), U1.M13 (GND), U1.M15 (CLK6), U1.M16 (CLK7), U1.N7 (GND), U1.N10 (GND), U1.P5 (GND), U1.P12 (GND), U1.R2 (GND), U1.R15 (GND), X1.2 (GND); also elsewhere on the board
unnamed: C46.1, C47.1, FB1.2, X1.1 (EN), X1.4 (V+)
unnamed: R15.2, X1.3 (OUT)
unnamed: R16.1, TP7.1, U1.H1 (DCLK)
unnamed: R18.2, U1.H12 (MSEL1)
unnamed: R20.2, U1.C1 (ASDO)
unnamed: R21.2, U1.D2 (nCSO)
unnamed: R23.1, U1.J3 (nCE)
unnamed: R24.1, U1.F16 (nCEO)
unnamed: R25.1, U1.F15 (CLKUSR)
unnamed: R26.1, R29.2, U1.H3 (TCK)

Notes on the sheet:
EP4CE6F17C8N EP4C, E: Cyclone IV, E 6: 6,272 LE F17: 256-FBGA C: Commercial temperature 8: speed grade 8 N: Lead-free VCCINT 1.2V
MSEL[2:0]: b000, Passive Serial b010, Active Serial x1, 3.3v
Power
Clock
Configuration interface
K15 <-> DPCLK4

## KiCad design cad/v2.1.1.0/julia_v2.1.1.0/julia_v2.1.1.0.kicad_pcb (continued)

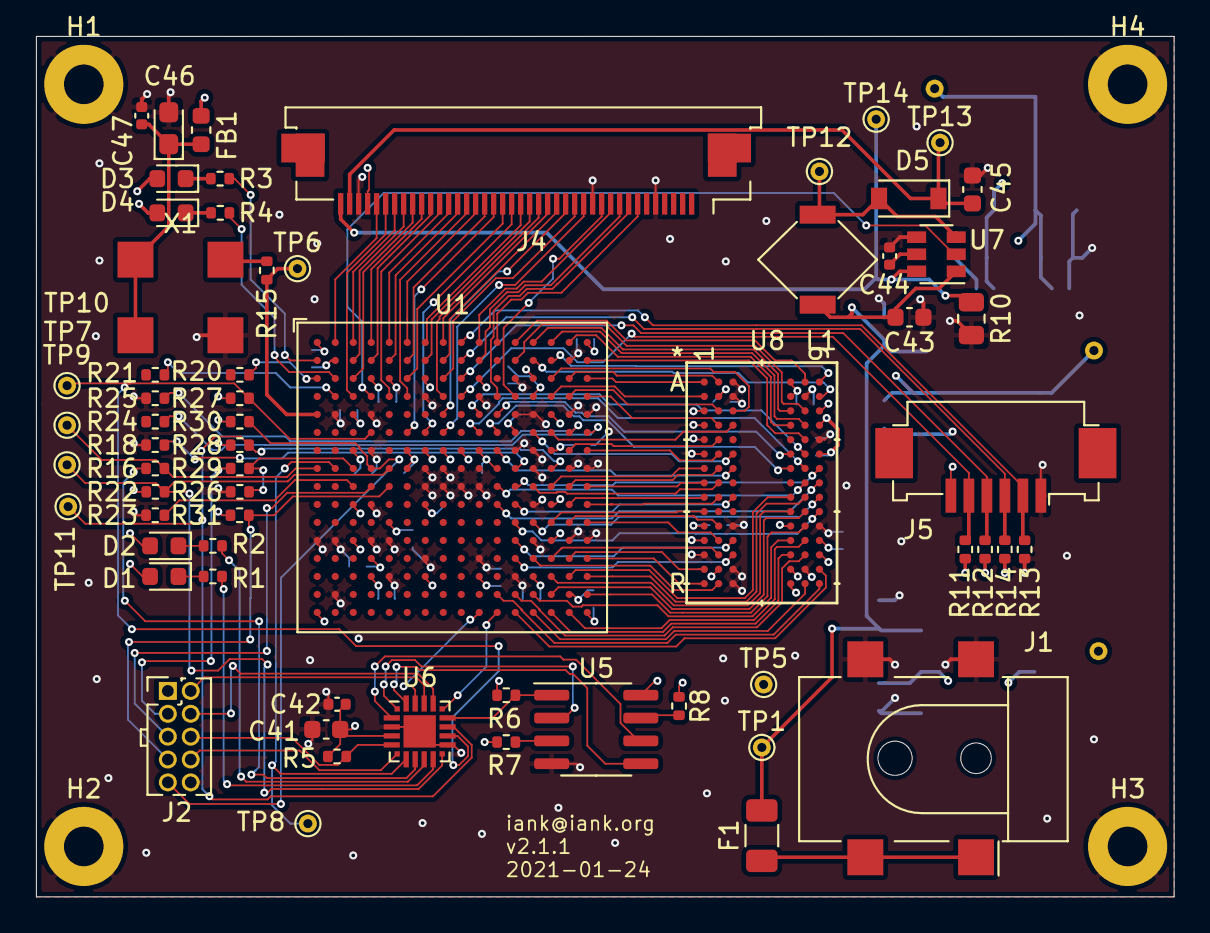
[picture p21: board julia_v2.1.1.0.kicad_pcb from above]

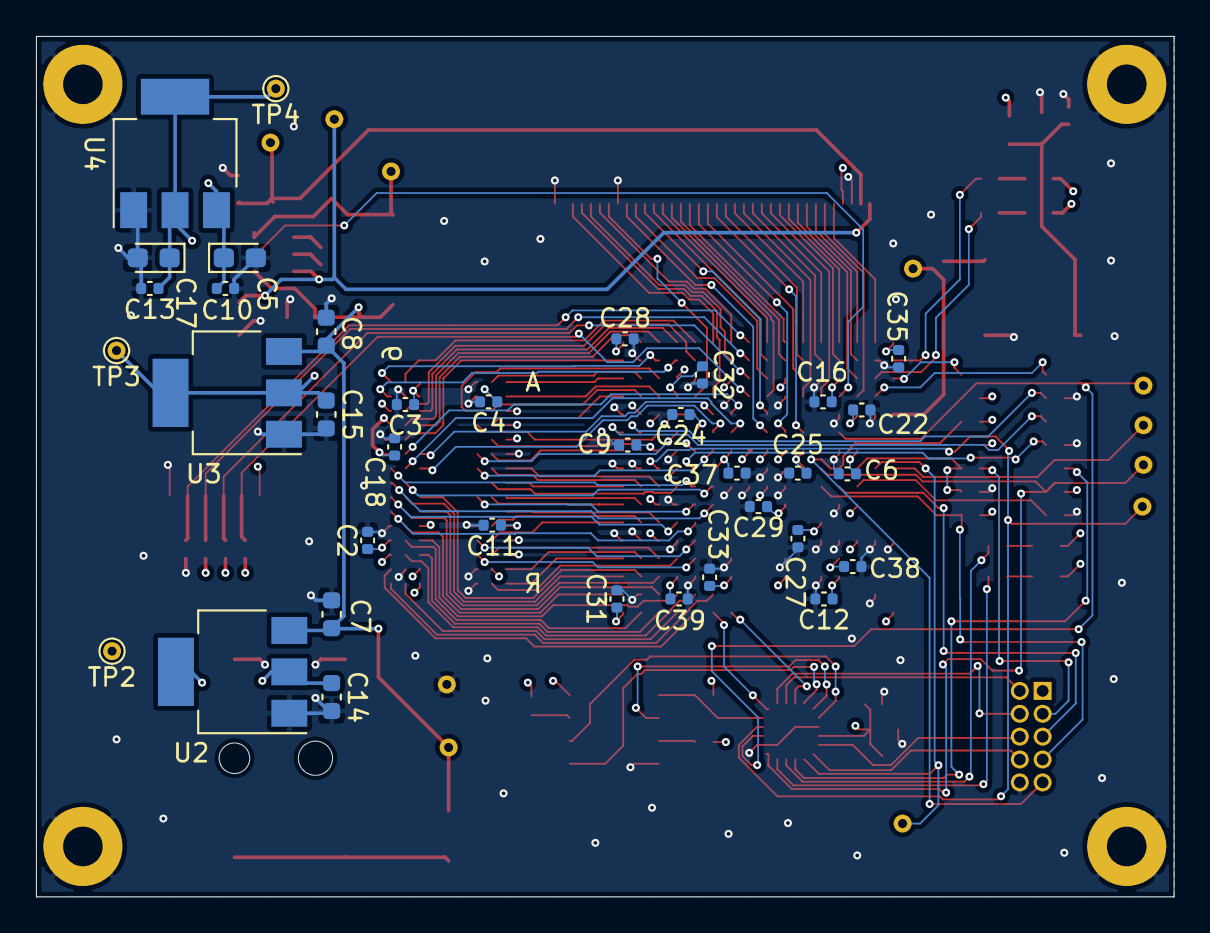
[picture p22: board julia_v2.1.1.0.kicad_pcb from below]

Board: 4 copper layers, 63.2 x 47.8 mm, 104 parts (36 on the bottom side), 140 nets.

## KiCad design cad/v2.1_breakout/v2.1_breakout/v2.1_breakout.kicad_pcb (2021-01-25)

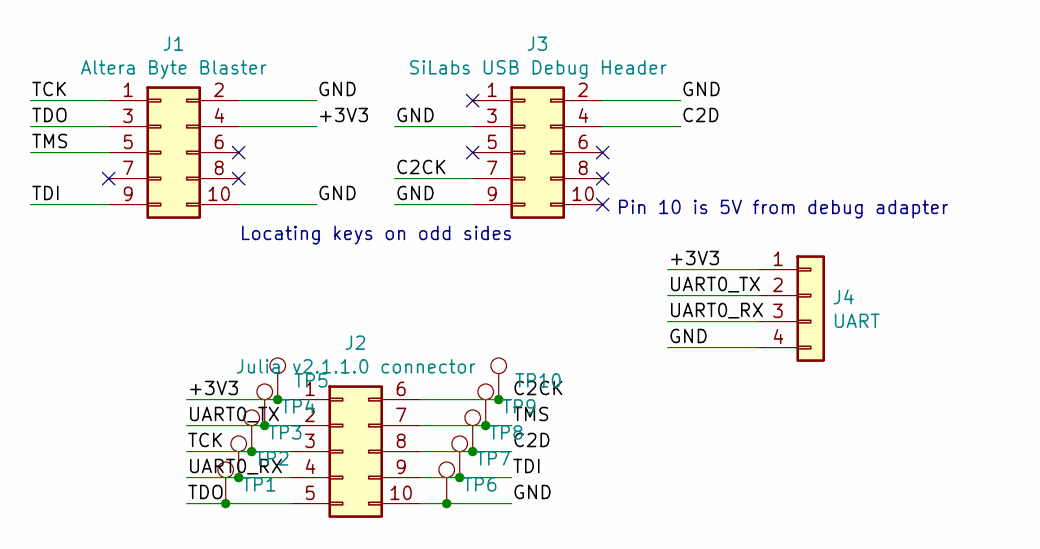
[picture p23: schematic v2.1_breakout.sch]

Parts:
J1: Altera Byte Blaster; PinHeader_2x05_P2.54mm_Vertical
J2: Julia v2.1.1.0 connector; PinHeader_2x05_P1.27mm_Vertical
J3: SiLabs USB Debug Header; PinHeader_2x05_P2.54mm_Vertical
J4: UART; PinHeader_1x04_P2.54mm_Vertical
TP1, TP2, TP3, TP4, TP5, TP6, TP7, TP8, TP9, TP10: TestPoint; TestPoint_THTPad_D1.0mm_Drill0.5mm

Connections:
/+3V3: J1.4, J2.1, J4.1, TP5.1
/C2CK: J2.6, J3.7, TP10.1
/C2D: J2.8, J3.4, TP8.1
/GND: J1.2, J1.10, J2.10, J3.2, J3.3, J3.9, J4.4, TP6.1
/TCK: J1.1, J2.3, TP3.1
/TDI: J1.9, J2.9, TP7.1
/TDO: J1.3, J2.5, TP1.1
/TMS: J1.5, J2.7, TP9.1
/UART0_RX: J2.4, J4.3, TP2.1
/UART0_TX: J2.2, J4.2, TP4.1

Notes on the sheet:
Locating keys on odd sides
Pin 10 is 5V from debug adapter

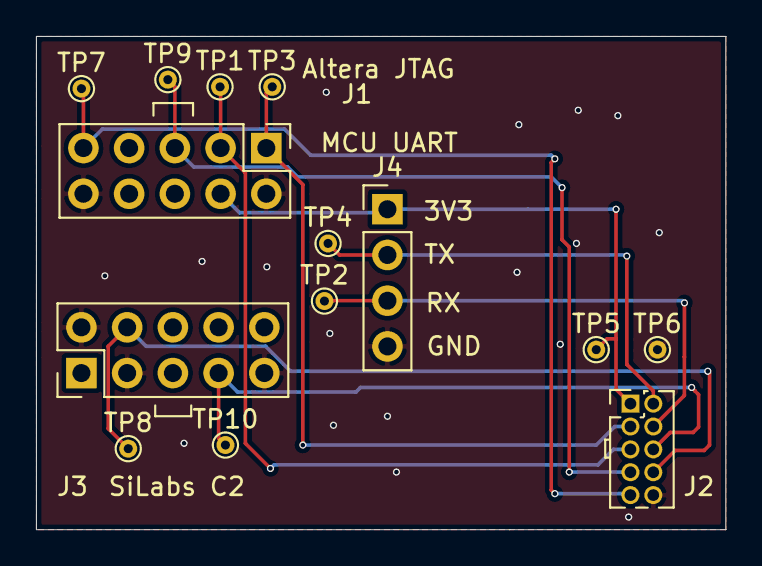
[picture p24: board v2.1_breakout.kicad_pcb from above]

Board: 2 copper layers, 38.3 x 27.4 mm, 14 parts (0 on the bottom side), 10 nets.

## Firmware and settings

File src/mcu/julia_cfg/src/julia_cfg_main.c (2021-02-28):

//-----------------------------------------------------------------------------
// Includes
//-----------------------------------------------------------------------------
#include <SI_EFM8BB2_Register_Enums.h>                // SFR declarations
#include <InitDevice.h>
#include <uart_0.h>

#include <util.h>
#include <spi_flash.h>

//-----------------------------------------------------------------------------
// Global Constants
//-----------------------------------------------------------------------------

/* */
// FPGA config outputs
SI_SBIT(CONFIG_N, SFR_P1, 2);     // P1.2 CONFIG_N
SI_SBIT(DCLK, SFR_P1, 5);         // P1.5 DCLK
SI_SBIT(DATA0, SFR_P1, 6);        // P1.6 DATA0

// FPGA config inputs
SI_SBIT(STATUS_N, SFR_P1, 1);     // P1.1 STATUS_N
SI_SBIT(CONF_DONE, SFR_P1, 0);    // P1.0 CONF_DONE

/* */

#define MCU_LED_OFF 1
#define MCU_LED_ON  0
SI_SBIT(MCU_LED_GREEN, SFR_P1, 3);// P1.3 MCU_LED1
SI_SBIT(MCU_LED_RED,   SFR_P1, 4);// P1.4 MCU_LED2

/* */

#define PAGE_LENGTH   256

#define CMD_ERASE 0
#define CMD_DUMP 1
#define CMD_WRITE 2
#define CMD_NONE 0xFF

#define CMD_MAGIC1 0xCA
#define CMD_MAGIC2 0xFE
#define CMD_LENGTH 3

#define RSP_MAGIC1 0x48
#define RSP_MAGIC2 0x49
#define RSP_FAIL 0x00
#define RSP_SUCCESS 0x01
#define RSP_CONTINUE 0x02
#define RSP_LENGTH 4

//-----------------------------------------------------------------------------
// Global Variables
//-----------------------------------------------------------------------------
SI_SEGMENT_VARIABLE(buffer[PAGE_LENGTH], uint8_t, SI_SEG_XDATA);
volatile bool tx_complete, rx_complete;

//-----------------------------------------------------------------------------
// SiLabs_Startup() Routine
// ----------------------------------------------------------------------------
// This function is called immediately after reset, before the initialization
// code is run in SILABS_STARTUP.A51 (which runs before main() ).
//-----------------------------------------------------------------------------
void SiLabs_Startup (void)
{
}

static uint8_t wait_for_command(void)
{
    uint16_t wait;

    wait = DELAY_10_MS * 50;

    rx_complete = false;
    UART0_readBuffer(buffer, CMD_LENGTH);
    while (!rx_complete && wait > 0)
    {
        delay(DELAY_10_MS);
        wait--;
    }

    if (!rx_complete)
        return CMD_NONE;

    if (!(buffer[0] == CMD_MAGIC1 && buffer[1] == CMD_MAGIC2))
        return CMD_NONE;

    return buffer[2];
}

static void respond(uint8_t cmd, uint8_t status)
{
    buffer[0] = RSP_MAGIC1;
    buffer[1] = RSP_MAGIC2;
    buffer[2] = cmd;
    buffer[3] = status;

    tx_complete = false;
    UART0_writeBuffer(buffer, RSP_LENGTH);
    while (!tx_complete);
}

static void bail(void)
{
    MCU_LED_RED = MCU_LED_ON;
    while (1) {}
}

static bool receive_and_write(void)
{
    uint32_t length, bytes_read, addr;
    uint16_t bytes_to_read;

    rx_complete = false;
    UART0_readBuffer(buffer, sizeof(uint32_t));
    while (!rx_complete);

    length = 0;
    length |= buffer[0]; length <<= 8;
    length |= buffer[1]; length <<= 8;
    length |= buffer[2]; length <<= 8;
    length |= buffer[3];

    addr = 0;
    if (!SPI_Program_Page(addr, buffer))
        return false;

    addr += PAGE_LENGTH;

    bytes_read = 0;
    while (bytes_read < length)
    {
        if (length - bytes_read > PAGE_LENGTH)
            bytes_to_read = PAGE_LENGTH;
        else
            bytes_to_read = length - bytes_read;

        respond(CMD_WRITE, RSP_CONTINUE);

        rx_complete = false;
        UART0_readBuffer(buffer, bytes_to_read>>2);
        while (!rx_complete);

        rx_complete = false;
        UART0_readBuffer(buffer + (bytes_to_read>>2), bytes_to_read - (bytes_to_read>>2));
        while (!rx_complete);

        bytes_read += bytes_to_read;

        if (!SPI_Program_Page(addr, buffer))
            return false;

        addr += bytes_to_read;
    }

    return true;
}

static bool read_and_transmit(void)
{
    uint32_t length, bytes_read, addr;
    uint16_t bytes_to_read;

    addr = 0;
    if (!SPI_Read_Page(addr, buffer))
        return false;

    length = 0;
    length |= buffer[0]; length <<= 8;
    length |= buffer[1]; length <<= 8;
    length |= buffer[2]; length <<= 8;
    length |= buffer[3];

    tx_complete = false;
    UART0_writeBuffer(buffer, 4);
    while (!tx_complete);

    addr += PAGE_LENGTH;

    bytes_read = 0;
    while (bytes_read < length)
    {
        if (length - bytes_read > PAGE_LENGTH)
            bytes_to_read = PAGE_LENGTH;
        else
            bytes_to_read = length - bytes_read;

        bytes_read += bytes_to_read;

        if (!SPI_Read_Page(addr, buffer))
            return false;

        tx_complete = false;
        UART0_writeBuffer(buffer, bytes_to_read>>2);
        while (!tx_complete);

        tx_complete = false;
        UART0_writeBuffer(buffer + (bytes_to_read>>2), bytes_to_read - (bytes_to_read>>2));
        while (!tx_complete);

        addr += bytes_to_read;
    }

    return true;
}

static void FPGA_bitstream_write(const uint8_t *buffer, uint16_t bytes)
{
    uint16_t i;
    uint8_t byte,j;
    for (i=0; i<bytes; i++)
    {
        // Clock out data LSB first. Bits are latched on rising edge of DCLK
        byte = buffer[i];
        for (j=0; j<8; j++)
        {
            DATA0 = byte & 1;
            DCLK = 1;
            DCLK = 0;
            byte = byte >> 1;
        }
    }
}

static bool configure_fpga()
{
    uint32_t length, bytes_read, addr;
    uint16_t bytes_to_read;
    uint16_t i;

    CONFIG_N = 1;
    delay(DELAY_10_MS);
    if (!STATUS_N)
        return false;

    CONFIG_N = 0;
    delay(DELAY_10_MS);

    addr = 0;
    if (!SPI_Read_Page(addr, buffer))
        return false;

    length = 0;
    length |= buffer[0]; length <<= 8;
    length |= buffer[1]; length <<= 8;
    length |= buffer[2]; length <<= 8;
    length |= buffer[3];

    addr += PAGE_LENGTH;

    // TODO: magic value to indicate config is valid

    if (STATUS_N || CONF_DONE)
        return false;

    // Begin configuration
    CONFIG_N = 1;
    while (!STATUS_N); // TODO: timeout

    bytes_read = 0;
    while (bytes_read < length)
    {
        if (length - bytes_read > PAGE_LENGTH)
            bytes_to_read = PAGE_LENGTH;
        else
            bytes_to_read = length - bytes_read;

        bytes_read += bytes_to_read;

        if (!SPI_Read_Page(addr, buffer))
            return false;

        FPGA_bitstream_write(buffer, bytes_to_read);
        if (!STATUS_N) // Failure
            return false;

        addr += bytes_to_read;
        MCU_LED_GREEN = ~MCU_LED_GREEN;
    }

    for (i=0; i<1024; i++) {
        DCLK = ~DCLK;
    }

    if (!CONF_DONE)
        return false;

    return true;
}

//-----------------------------------------------------------------------------
// main() Routine
// ----------------------------------------------------------------------------
int main (void)
{
    uint8_t cmd;

    SPI_CS_N = SPI_CS_N_DISABLE;
    MCU_LED_GREEN = MCU_LED_OFF;
    MCU_LED_RED = MCU_LED_OFF;
    CONFIG_N = 1;
    DCLK = 0;
    DATA0 = 0;

    enter_DefaultMode_from_RESET();
    IE_EA = 1;                                // Enable global interrupts

    UART0_init(UART0_RX_ENABLE, UART0_WIDTH_8, UART0_MULTIPROC_DISABLE);

    if (SPI_Flash_Init())
        MCU_LED_GREEN = MCU_LED_ON;
    else
        bail();

    while (1)
    {
        cmd = wait_for_command();
        MCU_LED_GREEN = MCU_LED_OFF;
        switch (cmd)
        {
          case CMD_ERASE:
            if (SPI_Flash_Erase()) {
                MCU_LED_GREEN = MCU_LED_ON;
                respond(CMD_ERASE, RSP_SUCCESS);
            }
            else {
                respond(CMD_ERASE, RSP_FAIL);
                bail();
            }

            break;
          case CMD_DUMP:
            if (read_and_transmit()) {
                MCU_LED_GREEN = MCU_LED_ON;
                respond(CMD_DUMP, RSP_SUCCESS);
            }
            else {
                respond(CMD_DUMP, RSP_FAIL);
                bail();
            }
            break;
          case CMD_WRITE:
            if (receive_and_write()) {
                MCU_LED_GREEN = MCU_LED_ON;
                respond(CMD_WRITE, RSP_SUCCESS);
            }
            else {
                respond(CMD_WRITE, RSP_FAIL);
                bail();
            }
            break;

          default:
            if (configure_fpga()) {
                MCU_LED_GREEN = MCU_LED_ON;
                goto shutdown_success;
            }
            else {
                bail();
            }
            break;
        }
    }

shutdown_success:
    // TODO: power down SPI flash
    // TODO: power down self

    while (1);
}

//-----------------------------------------------------------------------------
// UART ISR Callbacks
//-----------------------------------------------------------------------------
void UART0_receiveCompleteCb ()
{
    rx_complete = true;
}

void UART0_transmitCompleteCb ()
{
    tx_complete = true;
}

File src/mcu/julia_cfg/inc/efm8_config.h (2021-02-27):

/******************************************************************************
 * Copyright (c) 2014 by Silicon Laboratories Inc. All rights reserved.
 *
 * http://developer.silabs.com/legal/version/v11/Silicon_Labs_Software_License_Agreement.txt
 *****************************************************************************/
 
#ifndef __EFM8_CONFIG_H__
#define __EFM8_CONFIG_H__

#define EFM8PDL_UART0_USE_STDIO           0

#define EFM8PDL_SPI0_USE_BUFFER           1
#define EFM8PDL_SPI0_USE_PIPELINE         0

#define EFM8PDL_SPI0_TX_SEGTYPE           SI_SEG_DATA
#define EFM8PDL_SPI0_RX_SEGTYPE           SI_SEG_DATA

#endif // __EFM8_CONFIG_H__
 

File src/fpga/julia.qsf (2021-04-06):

# -------------------------------------------------------------------------- #
#
# Copyright (C) 2020  Intel Corporation. All rights reserved.
# Your use of Intel Corporation's design tools, logic functions 
# and other software and tools, and any partner logic 
# functions, and any output files from any of the foregoing 
# (including device programming or simulation files), and any 
# associated documentation or information are expressly subject 
# to the terms and conditions of the Intel Program License 
# Subscription Agreement, the Intel Quartus Prime License Agreement,
# the Intel FPGA IP License Agreement, or other applicable license
# agreement, including, without limitation, that your use is for
# the sole purpose of programming logic devices manufactured by
# Intel and sold by Intel or its authorized distributors.  Please
# refer to the applicable agreement for further details, at
# https://fpgasoftware.intel.com/eula.
#
# -------------------------------------------------------------------------- #
#
# Quartus Prime
# Version 20.1.1 Build 720 11/11/2020 SJ Lite Edition
# Date created = 15:14:29  February 12, 2021
#
# -------------------------------------------------------------------------- #
#
# Notes:
#
# 1) The default values for assignments are stored in the file:
#		julia_assignment_defaults.qdf
#    If this file doesn't exist, see file:
#		assignment_defaults.qdf
#
# 2) Altera recommends that you do not modify this file. This
#    file is updated automatically by the Quartus Prime software
#    and any changes you make may be lost or overwritten.
#
# -------------------------------------------------------------------------- #


set_global_assignment -name FAMILY "Cyclone IV E"
set_global_assignment -name DEVICE EP4CE6F17C8
set_global_assignment -name TOP_LEVEL_ENTITY julia
set_global_assignment -name ORIGINAL_QUARTUS_VERSION 20.1.1
set_global_assignment -name PROJECT_CREATION_TIME_DATE "15:14:29  FEBRUARY 12, 2021"
set_global_assignment -name LAST_QUARTUS_VERSION "20.1.1 Lite Edition"
set_global_assignment -name PROJECT_OUTPUT_DIRECTORY output_files
set_global_assignment -name MIN_CORE_JUNCTION_TEMP 0
set_global_assignment -name MAX_CORE_JUNCTION_TEMP 85
set_global_assignment -name DEVICE_FILTER_PACKAGE FBGA
set_global_assignment -name DEVICE_FILTER_PIN_COUNT 256
set_global_assignment -name ERROR_CHECK_FREQUENCY_DIVISOR 1
set_global_assignment -name NOMINAL_CORE_SUPPLY_VOLTAGE 1.2V
set_global_assignment -name EDA_SIMULATION_TOOL "ModelSim-Altera (Verilog)"
set_global_assignment -name EDA_TIME_SCALE "1 ps" -section_id eda_simulation
set_global_assignment -name EDA_OUTPUT_DATA_FORMAT "VERILOG HDL" -section_id eda_simulation
set_global_assignment -name EDA_GENERATE_FUNCTIONAL_NETLIST OFF -section_id eda_board_design_timing
set_global_assignment -name EDA_GENERATE_FUNCTIONAL_NETLIST OFF -section_id eda_board_design_symbol
set_global_assignment -name EDA_GENERATE_FUNCTIONAL_NETLIST OFF -section_id eda_board_design_signal_integrity
set_global_assignment -name EDA_GENERATE_FUNCTIONAL_NETLIST OFF -section_id eda_board_design_boundary_scan
set_location_assignment PIN_E1 -to PLD_CLOCKINPUT
set_location_assignment PIN_B1 -to LEDG[0]
set_location_assignment PIN_C2 -to LEDG[1]
set_location_assignment PIN_C14 -to S_DQ[25]
set_location_assignment PIN_D14 -to S_DQ[28]
set_location_assignment PIN_A13 -to S_DQ[22]
set_location_assignment PIN_B13 -to S_DQ[19]
set_location_assignment PIN_A14 -to S_DQ[18]
set_location_assignment PIN_B14 -to S_DQ[21]
set_location_assignment PIN_E11 -to S_ADDR[2]
set_location_assignment PIN_E10 -to S_DQM[2]
set_location_assignment PIN_A12 -to S_DQ[23]
set_location_assignment PIN_B12 -to S_DQ[20]
set_location_assignment PIN_F10 -to S_ADDR[0]
set_location_assignment PIN_F11 -to S_ADDR[10]
set_location_assignment PIN_A15 -to S_DQ[17]
set_location_assignment PIN_G16 -to S_DQM[3]
set_location_assignment PIN_G15 -to S_DQ[31]
set_location_assignment PIN_F13 -to S_ADDR[3]
set_location_assignment PIN_B16 -to S_DQ[16]
set_location_assignment PIN_F14 -to S_DQ[30]
set_location_assignment PIN_D16 -to S_DQ[29]
set_location_assignment PIN_D15 -to S_DQ[27]
set_location_assignment PIN_G11 -to S_ADDR[6]
set_location_assignment PIN_C16 -to S_DQ[26]
set_location_assignment PIN_C15 -to S_DQ[24]
set_location_assignment PIN_N13 -to S_DQ[15]
set_location_assignment PIN_M12 -to S_DQ[9]
set_location_assignment PIN_L12 -to S_DQM[0]
set_location_assignment PIN_K12 -to S_ADDR[9]
set_location_assignment PIN_N14 -to S_DQ[12]
set_location_assignment PIN_P15 -to S_BA[0]
set_location_assignment PIN_P16 -to S_CS_N
set_location_assignment PIN_R16 -to S_DQ[7]
set_location_assignment PIN_K11 -to S_ADDR[11]
set_location_assignment PIN_N16 -to S_DQ[13]
set_location_assignment PIN_N15 -to S_DQ[11]
set_location_assignment PIN_L14 -to S_DQM[1]
set_location_assignment PIN_L13 -to S_RAS_N
set_location_assignment PIN_L16 -to S_DQ[10]
set_location_assignment PIN_L15 -to S_DQ[8]
set_location_assignment PIN_J11 -to S_BA[1]
set_location_assignment PIN_K16 -to S_CKE
set_location_assignment PIN_K15 -to S_CLK
set_location_assignment PIN_J16 -to S_ADDR[7]
set_location_assignment PIN_J15 -to S_ADDR[5]
set_location_assignment PIN_J14 -to S_ADDR[4]
set_location_assignment PIN_J12 -to S_ADDR[1]
set_location_assignment PIN_J13 -to S_ADDR[8]
set_location_assignment PIN_R11 -to S_DQ[2]
set_location_assignment PIN_R12 -to S_DQ[3]
set_location_assignment PIN_T12 -to S_DQ[4]
set_location_assignment PIN_R13 -to S_DQ[6]
set_location_assignment PIN_T13 -to S_DQ[0]
set_location_assignment PIN_T14 -to S_DQ[1]
set_location_assignment PIN_T15 -to S_DQ[5]
set_location_assignment PIN_N12 -to S_DQ[14]
set_location_assignment PIN_R14 -to S_WE_N
set_location_assignment PIN_P14 -to S_CAS_N
set_location_assignment PIN_A8 -to RGB[19]
set_location_assignment PIN_B8 -to RGB[20]
set_location_assignment PIN_C8 -to RGB[22]
set_location_assignment PIN_D8 -to RGB[18]
set_location_assignment PIN_E8 -to RGB[21]
set_location_assignment PIN_F8 -to RGB[23]
set_location_assignment PIN_A7 -to RGB[16]
set_location_assignment PIN_B7 -to RGB[17]
set_location_assignment PIN_F6 -to RGB[13]
set_location_assignment PIN_F7 -to RGB[15]
set_location_assignment PIN_C6 -to RGB[14]
set_location_assignment PIN_B6 -to RGB[12]
set_location_assignment PIN_A6 -to RGB[11]
set_location_assignment PIN_A5 -to RGB[8]
set_location_assignment PIN_A2 -to RGB[0]
set_location_assignment PIN_B5 -to RGB[9]
set_location_assignment PIN_A4 -to RGB[5]
set_location_assignment PIN_B4 -to RGB[6]
set_location_assignment PIN_D5 -to RGB[7]
set_location_assignment PIN_D6 -to RGB[10]
set_location_assignment PIN_C3 -to RGB[4]
set_location_assignment PIN_B3 -to RGB[3]
set_location_assignment PIN_A3 -to RGB[2]
set_location_assignment PIN_D3 -to RGB[1]
set_location_assignment PIN_D12 -to LCDCLK
set_location_assignment PIN_A11 -to DEN
set_location_assignment PIN_D11 -to VSD
set_location_assignment PIN_B10 -to HSD
set_location_assignment PIN_A10 -to STBYB
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

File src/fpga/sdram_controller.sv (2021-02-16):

// https://github.com/hdl-util/sdram-controller/
module sdram_controller #(
    parameter int CLK_RATE, // Speed of your sdram clock in Hz
	parameter int READ_BURST_LENGTH = 1, // 1, 2, 4, 8, or 256 (full page). All other values are reserved.
	parameter int WRITE_BURST = 1, // OFF = Single write mode, ON = Burst write mode (same length as read burst)
	parameter int BANK_ADDRESS_WIDTH,
	parameter int ROW_ADDRESS_WIDTH,
	parameter int COLUMN_ADDRESS_WIDTH,
	parameter int DATA_WIDTH,
	parameter int DQM_WIDTH,
	parameter int CAS_LATENCY,
	// All parameters below are measured in floating point seconds (i.e. 1ns = 1E-9).
	// They should be obtained from the datasheet for your chip.
	parameter real ROW_CYCLE_TIME,
	parameter real RAS_TO_CAS_DELAY,
	parameter real PRECHARGE_TO_REFRESH_OR_ROW_ACTIVATE_SAME_BANK_TIME,
	parameter real ROW_ACTIVATE_TO_ROW_ACTIVATE_DIFFERENT_BANK_TIME,
	parameter real ROW_ACTIVATE_TO_PRECHARGE_SAME_BANK_TIME,
	// Some SDRAM chips require a minimum clock stability time prior to initialization. If it's not in the datasheet, you can try setting it to 0.
	parameter real MINIMUM_STABLE_CONDITION_TIME,
	parameter real MODE_REGISTER_SET_CYCLE_TIME,
	parameter real WRITE_RECOVERY_TIME,
	parameter real AVERAGE_REFRESH_INTERVAL_TIME,

	// Please do not set these parameters
	parameter int USER_ADDRESS_WIDTH = BANK_ADDRESS_WIDTH + ROW_ADDRESS_WIDTH + COLUMN_ADDRESS_WIDTH,
	parameter int CHIP_ADDRESS_WIDTH = (ROW_ADDRESS_WIDTH > COLUMN_ADDRESS_WIDTH ? ROW_ADDRESS_WIDTH : COLUMN_ADDRESS_WIDTH)
) (
	input logic clk,

	// 0 = Idle
	// 1 = Write (with Auto Precharge)
	// 2 = Read (with Auto Precharge)
	// 3 = Self Refresh (TODO)
	input logic [1:0] command,
	input logic [USER_ADDRESS_WIDTH-1:0] data_address,
	input logic [DATA_WIDTH-1:0] data_write,
	output logic [DATA_WIDTH-1:0] data_read,
	output logic data_read_valid = 1'b0, // goes high when a burst-read is ready
	output logic data_write_done = 1'b0, // goes high once the first write of a burst-write / single-write is done

	// These ports should be connected directly to the SDRAM chip
	output logic clock_enable = 1'b0,
	output logic [BANK_ADDRESS_WIDTH-1:0] bank_activate,
	output logic [CHIP_ADDRESS_WIDTH-1:0] address,
	output logic chip_select,
	output logic row_address_strobe,
	output logic column_address_strobe,
	output logic write_enable,
	output logic [DQM_WIDTH-1:0] dqm,
	inout wire [DATA_WIDTH-1:0] dq
);

localparam int ROW_CYCLE_CLOCKS = $unsigned(integer'(ROW_CYCLE_TIME * CLK_RATE));
localparam int RAS_TO_CAS_DELAY_CLOCKS = $unsigned(integer'(RAS_TO_CAS_DELAY * CLK_RATE));
localparam int PRECHARGE_TO_REFRESH_OR_ROW_ACTIVATE_SAME_BANK_CLOCKS = $unsigned(integer'(PRECHARGE_TO_REFRESH_OR_ROW_ACTIVATE_SAME_BANK_TIME * CLK_RATE));
localparam int ROW_ACTIVATE_TO_ROW_ACTIVATE_DIFFERENT_BANK_CLOCKS = $unsigned(integer'(ROW_ACTIVATE_TO_ROW_ACTIVATE_DIFFERENT_BANK_TIME * CLK_RATE));
localparam int ROW_ACTIVATE_TO_PRECHARGE_SAME_BANK_CLOCKS = $unsigned(integer'(ROW_ACTIVATE_TO_PRECHARGE_SAME_BANK_TIME * CLK_RATE));
localparam int MINIMUM_STABLE_CONDITION_CLOCKS = $unsigned(integer'(MINIMUM_STABLE_CONDITION_TIME * CLK_RATE));

localparam int MODE_REGISTER_SET_CLOCKS = $unsigned(integer'(MODE_REGISTER_SET_CYCLE_TIME * CLK_RATE));
localparam int WRITE_RECOVERY_CLOCKS = $unsigned(integer'(WRITE_RECOVERY_TIME * CLK_RATE));

localparam int AVERAGE_REFRESH_INTERVAL_CLOCKS = $unsigned(integer'(AVERAGE_REFRESH_INTERVAL_TIME * CLK_RATE));

localparam bit [2:0] STATE_UNINIT = 3'd0;
localparam bit [2:0] STATE_IDLE = 3'd1;
localparam bit [2:0] STATE_WRITING = 3'd2;
localparam bit [2:0] STATE_READING = 3'd3;
localparam bit [2:0] STATE_WAITING = 3'd4;
localparam bit [2:0] STATE_PRECHARGE = 3'd5;
logic [2:0] state = STATE_UNINIT;

localparam int REFRESH_TIMER_WIDTH = $clog2(AVERAGE_REFRESH_INTERVAL_CLOCKS + 1);
localparam bit [REFRESH_TIMER_WIDTH-1:0] REFRESH_TIMER_END = REFRESH_TIMER_WIDTH'(AVERAGE_REFRESH_INTERVAL_CLOCKS);
logic [REFRESH_TIMER_WIDTH-1:0] refresh_timer = REFRESH_TIMER_WIDTH'(0);

assign dqm = 4'b0;

localparam bit [3:0] CMD_BANK_ACTIVATE = 4'd0;
localparam bit [3:0] CMD_BANK_PRECHARGE = 4'd1;
localparam bit [3:0] CMD_PRECHARGE_ALL = 4'd2;
localparam bit [3:0] CMD_WRITE = 4'd3;
localparam bit [3:0] CMD_READ = 4'd4;
localparam bit [3:0] CMD_MODE_REGISTER_SET = 4'd5;
localparam bit [3:0] CMD_NO_OP = 4'd6;
localparam bit [3:0] CMD_BURST_STOP = 4'd7;
localparam bit [3:0] CMD_AUTO_REFRESH = 4'd8;

logic [3:0] internal_command = CMD_NO_OP;

always_ff @(posedge clk)
begin
	// TODO: abort a read/write and refresh if it's taking too long (i.e. full-page)
	if (state == STATE_WAITING && internal_command == CMD_AUTO_REFRESH) // Refresh will always occur from an idle state
		refresh_timer <= REFRESH_TIMER_WIDTH'(0);
	if (state == STATE_UNINIT)
		refresh_timer <= REFRESH_TIMER_WIDTH'(0);
	else
		refresh_timer <= refresh_timer + 1'd1;
end

localparam int COUNTER_WIDTH = $clog2(MINIMUM_STABLE_CONDITION_CLOCKS + 1); // Row cycle time is the longest delay
logic [COUNTER_WIDTH-1:0] countdown = COUNTER_WIDTH'(0);

// Jump from waiting to a specified state
logic [2:0] destination_state = STATE_UNINIT;

// "Step" counter used for burst write/read counting and initialization steps. Must be at least 3 bits wide.
localparam int STEP_WIDTH = $clog2(READ_BURST_LENGTH == 1 ? $unsigned(8) : $unsigned(READ_BURST_LENGTH + 3 + CAS_LATENCY));
logic [STEP_WIDTH-1:0] step = STEP_WIDTH'(0);

logic [DATA_WIDTH-1:0] internal_dq = DATA_WIDTH'(0);
assign dq = state == STATE_WRITING ? internal_dq : {DATA_WIDTH{1'bz}}; // Tri-State driver


assign chip_select = !(internal_command != CMD_NO_OP);
assign row_address_strobe = !(internal_command == CMD_BANK_ACTIVATE || internal_command == CMD_BANK_PRECHARGE || internal_command == CMD_PRECHARGE_ALL || internal_command == CMD_MODE_REGISTER_SET || internal_command == CMD_AUTO_REFRESH);
assign column_address_strobe = !(internal_command == CMD_WRITE || internal_command == CMD_READ || internal_command == CMD_MODE_REGISTER_SET || internal_command == CMD_AUTO_REFRESH);
assign write_enable = !(internal_command == CMD_BANK_PRECHARGE || internal_command == CMD_PRECHARGE_ALL || internal_command == CMD_WRITE || internal_command == CMD_MODE_REGISTER_SET || internal_command == CMD_BURST_STOP);

logic pending_precharge = 1'd0;

logic [ROW_ADDRESS_WIDTH-1:0] last_row_address;
logic bank_or_row_differs;
assign bank_or_row_differs = bank_activate != data_address[USER_ADDRESS_WIDTH - 1 : USER_ADDRESS_WIDTH - BANK_ADDRESS_WIDTH] || last_row_address != data_address[USER_ADDRESS_WIDTH - 1 - BANK_ADDRESS_WIDTH : USER_ADDRESS_WIDTH - BANK_ADDRESS_WIDTH - ROW_ADDRESS_WIDTH];
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

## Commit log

2020-11-01 LCD/memory Breakout
    [lcd_breakout.GBL, lcd_breakout.GBO, lcd_breakout.GBP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]
2020-11-01 Board image URL
2020-11-01 Higher resolution board image
2020-11-29 (Buggy) verilog PoC, drives screen and SRAM
    [julia.qsf]
2020-11-29 Move v1.0.0.0 files into version directory
    [lcd_breakout.GBL, lcd_breakout.GBO, lcd_breakout.GBP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]
2020-11-29 Fix J5 and D1 footprints in version v1.1.0.0 (not verified)
    [lcd_breakout.sch]
2020-12-03 v2 WiP
    [julia_v2.sch]
2020-12-04 v2 update, power and config chip
    [julia_v2.sch]
2020-12-04 Julia v2.0.0.0 schematic and BOM
    [julia_v2.sch]
2020-12-06 Julia v2.0.0.0 board
    [julia_v2.brd, julia_v2.sch]
2020-12-06 CAM files for v2.0.0.0
    [julia_v2.GBL, julia_v2.GBO, julia_v2.GBP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]
2020-12-26 Update verilog for v2.0.0.0 board
2021-01-04 v2.1.0.0 schematic
    [julia_config.sch, julia_fpga.sch, julia_io.sch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]
2021-01-06 Swap FAN5333BSX backlight driver for TPS61165
    [julia_io.sch, julia_lcd.sch]
2021-01-08 v2.1.0.0: changed connector, ERC, annotation/footprint assignment
    [julia_config.sch, julia_fpga.sch, julia_io.sch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]
2021-01-09 Layout begun
    [julia_fpga.sch, julia_v2.1.0.0.kicad_pcb]
2021-01-09 Layout complete(?)
    [julia_fpga.sch, julia_power.sch, julia_v2.1.0.0.kicad_pcb]
2021-01-09 v2.1.0.0 gerber files
    [julia_v2.1.0.0-B_Cu.gbr, julia_v2.1.0.0-B_Mask.gbr, julia_v2.1.0.0-B_Paste.gbr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]
2021-01-10 Programmer breakout board for v2.1
    [v2.1_breakout-B_Cu.gbr, v2.1_breakout-B_Mask.gbr, v2.1_breakout-B_Paste.gbr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]
2021-01-28 v2.1.1.0 BOM
2021-02-12 Clean up v2.1.1.0 FPGA sheet; update BOM
    [julia_fpga.sch]
2021-02-12 Clean up old versions, add pdf/png outputs
    [julia_config.sch, julia_fpga.sch, julia_io.sch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]
2021-02-12 Empty design w/ pin assignments
2021-02-13 Test fixtures for LCD and SDRAM controllers
    [julia.qsf, sdr.v]
2021-02-13 SDRAM to display FIFO (simulates but doesn't work)
    [julia.qsf, sdram_controller.sv]
2021-02-13 Fix refresh timing (still doesn't work in HW)
    [julia.qsf, sdram_controller.sv]
2021-02-17 Sweep SDRAM init / frame reading under the rug
2021-02-17 Split mem init out of frame reader
2021-02-18 (probably working) arbitration btwn frame reader and processor
2021-02-21 Update barrel jack footprint
    [julia_v2.1.1.0.kicad_pcb]
2021-02-21 Several more 3d models
    [julia_config.sch, julia_lcd.sch, julia_v2.1.1.0.kicad_pcb]
2021-02-21 Updated 3d rendering
    [julia_fpga.sch, julia_io.sch, julia_v2.1.1.0.kicad_pcb]
2021-02-21 combine a couple signals
2021-02-26 MCU: UART0 demo
2021-02-27 SPI flash init
2021-02-27 Move SPI flash routines out of main
2021-02-27 Refactor SPI flash init
2021-02-27 Increase SPI clock to 1.5MHz
2021-04-06 Color map hack for immediate feedback on touch; blank screen/backlight after couple minutes

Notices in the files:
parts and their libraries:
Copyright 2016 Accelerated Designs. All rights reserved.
